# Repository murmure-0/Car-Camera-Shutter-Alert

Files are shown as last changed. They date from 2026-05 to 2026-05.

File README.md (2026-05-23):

# 🚗 Car Camera Shutter Alert

> 基于瑞芯微 RV1106 + STM32L4 的智能车载安全驾驶监控系统 — 集疲劳检测、手势识别、多传感器融合与 HUD 显示于一体


[]()
[]()
[]()

---

## 📖 项目简介

Car Camera Shutter Alert 是一套面向嵌入式车载场景的智能安全驾驶辅助系统，运行在瑞芯微 RV1106 嵌入式平台与 STM32L431 微控制器之上。系统通过摄像头实时采集驾驶员面部图像，利用 NPU 加速的深度学习模型进行人脸检测与关键点提取，计算 EAR（眼睛纵横比）、MAR（嘴巴纵横比）、PERCLOS 等疲劳指标，实现实时疲劳驾驶预警。同时集成百度手势识别 API，支持通过手势控制音乐播放，提升驾驶安全性与便利性。

### ✨ 核心特性

- **🧠 实时疲劳检测** — 基于 RetinaFace + PFLD 的多指标疲劳判定（EAR/MAR/PERCLOS/连续闭眼/连续张嘴）
- **🤚 手势识别控制** — 百度云端手势识别 API，支持握拳暂停、张手播放、食指上一首、数字二下一首
- **📹 视频录制** — 摄像头实时预览与录制状态管理
- **🗺️ GPS 定位** — GPS 模块 NMEA 解析 + 百度静态地图展示
- **🌡️ 环境监测** — 温湿度（AHT30）、加速度/陀螺仪（MPU6050）、电压/电流（INA226）、电池/霍尔传感器
- **🎵 音乐播放** — 本地音乐播放器，支持手势控制
- **📊 HUD 仪表盘** — 800×480 暗色主题 UI，人工地平仪、折线图、地图背景等 HUD 组件
- **🔌 双 MCU 串口通信** — STM32 与 RV1106 通过 UART JSON 协议实时交互传感器数据与控制指令
- **⚙️ 步进电机控制** — 支持摄像头遮挡盖板自动开合

---

## 🔧 硬件外观

<p align="center">
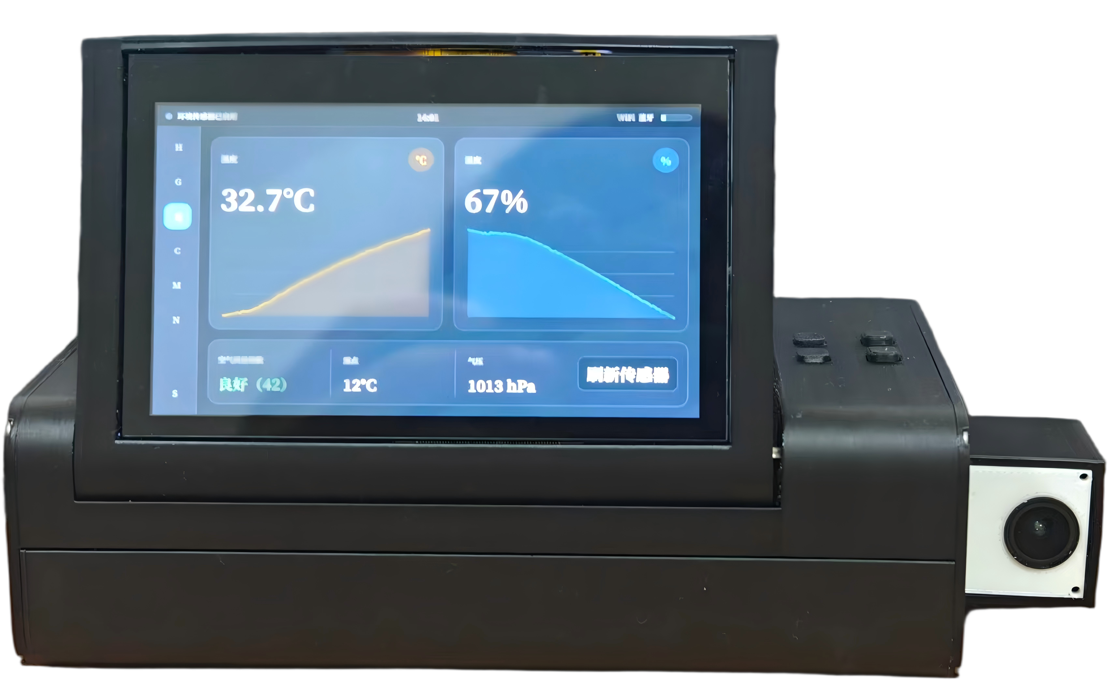
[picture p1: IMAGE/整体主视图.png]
Front View
  
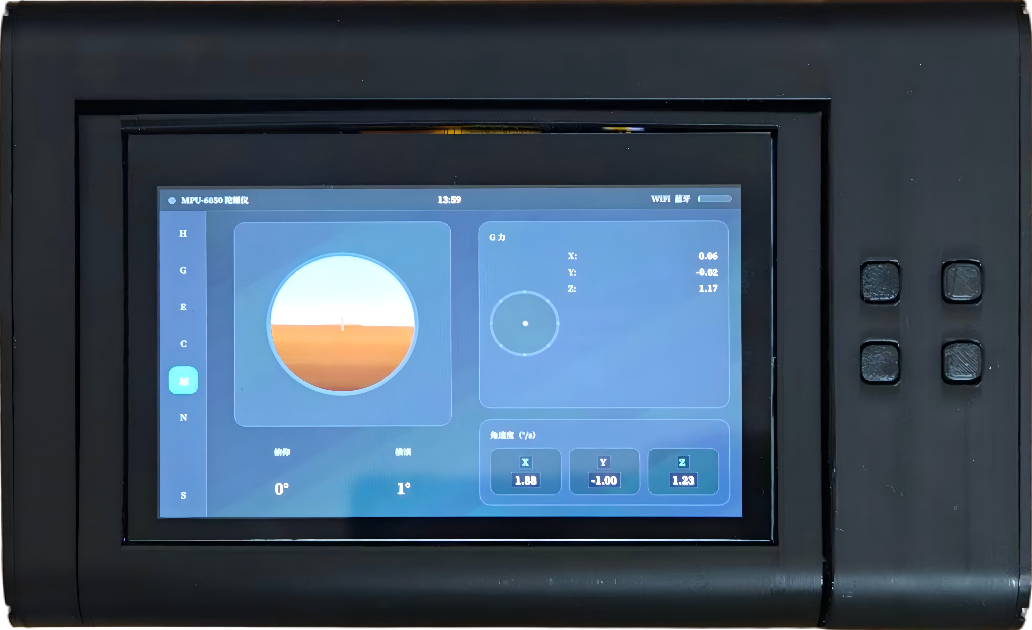
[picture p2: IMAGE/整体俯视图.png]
Top View
  
</p>

---

## 🏗️ 系统架构

```
┌─────────────────────────────────────────────────────────────────┐
│                    RV1106 主控板 (Linux)                         │
│  ┌──────────────────────────────────────────────────────────┐    │
│  │              Qt5 车机 UI (qt_car_ui)                      │   │
│  │  ┌──────┐ ┌──────┐ ┌──────┐ ┌──────┐ ┌──────┐ ┌──────┐   │    │
│  │  │仪表盘 │ │ GPS  │ │环境  │ │摄像头 │ │运动  │ │设置   │  │    │
│  │  └──────┘ └──────┘ └──────┘ └──┬───┘ └──────┘ └──────┘   │   │
│  └──────────────────────────────┼───────────────────────────┘   │
│                                 │                                │
│  ┌──────────────────────────────┼───────────────────────────┐   │
│  │        AI 推理引擎           │                           │   │
│  │  ┌─────────────┐  ┌─────────┴────────┐                  │   │
│  │  │ RetinaFace  │  │ PFLD 关键点检测  │                  │   │
│  │  │ 人脸检测    │  │ 106点关键点      │                  │   │
│  │  └──────┬──────┘  └────────┬─────────┘                  │   │
│  │         └────────┬─────────┘                             │   │
│  │                  ▼                                        │   │
│  │         ┌─────────────────┐                              │   │
│  │         │  疲劳指标计算    │                              │   │
│  │         │  EAR/MAR/PERCLOS│                              │   │
│  │         └─────────────────┘                              │   │
│  └──────────────────────────────────────────────────────────┘   │
│  ┌──────────────────────────────────────────────────────────┐   │
│  │  百度手势识别 API (BaiduGestureClient)                    │   │
│  └──────────────────────────────────────────────────────────┘   │
│                                                                 │
│  UART (ttyS0/ttyS1, 115200bps) ◄──── JSON 协议 ────►          │
└─────────────────────────────────────────────────────────────────┘
                              │
                              ▼
┌─────────────────────────────────────────────────────────────────┐
│                  STM32L431 传感器控制板 (FreeRTOS)               │
│  ┌────────┐ ┌────────┐ ┌────────┐ ┌────────┐ ┌────────┐         │
│  │MPU6050 │ │ AHT30  │ │ INA226 │ │  GPS   │ │步进电机│          │
│  │加速度  │ │温湿度  │ │电压电流│ │定位    │ │遮挡盖  │            │
│  └────────┘ └────────┘ └────────┘ └────────┘ └────────┘         │
│  ┌────────┐ ┌────────┐ ┌────────┐                               │
│  │ADC采集 │ │按键    │ │LED指示 │                                │
│  │电池/霍尔│ │开关机  │ │状态    │                                │
│  └────────┘ └────────┘ └────────┘                               │
└─────────────────────────────────────────────────────────────────┘
```

---

## 📁 项目结构

```
Car-Camera-Shutter-Alert/
├── qt_car_ui/                      # RV1106 端 Qt5 车机 UI 应用
│   ├── main.cpp                    # 应用入口
│   ├── mainwindow.h/cpp/ui         # 主窗口（页面路由、缩放适配、全局状态）
│   ├── baidu_gesture_client.h/cpp  # 百度手势识别 API 客户端
│   ├── camera/
│   │   ├── camera_service.h        # 摄像头硬件服务（MPI/ISP）
│   │   └── luckfox_mpi.cc          # Luckfox Pico MPI 封装
│   ├── pages/
│   │   ├── camerapage.h/cpp        # 摄像头页面（预览、疲劳检测、手势识别）
│   │   ├── dashboardpage.h/cpp     # 仪表盘页面（地图、音乐、系统监控）
│   │   ├── gpspage.h/cpp           # GPS 定位页面
│   │   ├── environmentpage.h/cpp   # 环境监测页面
│   │   ├── motionpage.h/cpp        # 运动姿态页面
│   │   ├── connectivitypage.h/cpp  # 网络连接页面
│   │   ├── settingspage.h/cpp      # 系统设置页面
│   │   ├── hudwidgets.h            # HUD 自定义控件（地平仪、折线图、预览等）
│   │   └── camerahud.h/cpp         # 摄像头 HUD 叠加层
│   ├── luckfox_pico_yolov5/
│   │   ├── include/
│   │   │   ├── yolov5.h            # YOLOv5 RKNN 模型上下文
│   │   │   ├── postprocess.h       # YOLOv5 后处理
│   │   │   ├── fatigue_runner.h    # 疲劳检测推理引擎
│   │   │   └── handyolo_runner.h   # 手部 YOLO 检测器
│   │   └── src/
│   │       ├── yolov5_runner.cpp
│   │       ├── fatigue_runner.cpp
│   │       └── handyolo_runner.cpp
│   ├── include/                    # 第三方库与平台头文件
│   │   ├── 3rdparty/               # RKNPU2、librga、DMA/DRM 分配器
│   │   ├── common/                 # ISP、sample_comm 公共代码
│   │   └── include/                # Rockchip MPI、RGA、RKAIQ 等平台头文件
│   ├── docs/
│   │   ├── camera_page_flow.md     # 摄像头页面运行流程分析
│   │   └── thread_resource_analysis.md  # 线程资源管理分析
│   └── qt_car_ui.pro               # Qt 项目文件
│
├── rv1106_sensor/                  # STM32L431 传感器控制板固件
│   ├── Core/
│   │   ├── Inc/                    # 头文件
│   │   │   ├── main.h
│   │   │   ├── bsp_power.h         # 电源管理
│   │   │   ├── mpu6050.h           # MPU6050 IMU 驱动
│   │   │   ├── aht30.h             # AHT30 温湿度驱动
│   │   │   ├── ina226.h            # INA226 功率监测驱动
│   │   │   ├── gps_module.h        # GPS 模块驱动
│   │   │   ├── stepper.h           # 步进电机驱动
│   │   │   ├── soft_i2c.h          # 软件 I2C 驱动
│   │   │   ├── key_handler.h       # 按键处理
│   │   │   ├── task_queue.h        # FreeRTOS 消息队列
│   │   │   ├── business_handler.h  # 业务逻辑处理
│   │   │   ├── protocol.h          # 串口通信协议
│   │   │   └── json_parser.h       # JSON 解析器
│   │   └── Src/                    # 源文件
│   ├── Drivers/                    # STM32 HAL/CMSIS 库
│   ├── MDK-ARM/                    # Keil MDK 工程文件
│   ├── README.md                   # STM32 子项目说明
│   └── PROTOCOL.md                 # STM32-RV1106 通信协议文档
│
├── 3d_model_assets/                # SolidWorks 3D 外壳模型
├── PCB/                            # PCB 工程文件
├── LICENSE                         # MIT 许可证
├── CONTRIBUTING.md                 # 贡献指南
└── README.md                       # 本文件
```

---

## 🚀 快速开始

### 前置条件

#### RV1106 端 (Qt5 UI)

- **硬件**: Luckfox Pico RV1106 开发板
- **交叉编译工具链**: arm-linux-gnueabihf-gcc
- **Qt5**: 交叉编译的 Qt5 for ARM (含 network、serialport 模块)
- **RKNN SDK**: rknpu2 运行时库 (armhf-uclibc)
- **Rockchip MPI**: librockit、librockchip_mpp、librga、librkaiq
- **OpenCV**: 交叉编译的 OpenCV for ARM
- **百度智能云 API Key**: 用于手势识别服务

#### STM32 端 (传感器固件)

- **硬件**: STM32L431RCT6 最小系统板
- **IDE**: Keil MDK-ARM v5
- **SDK**: STM32L4xx HAL Driver + CMSIS
- **RTOS**: FreeRTOS

### 编译与部署

#### 1. Qt5 车机 UI 编译

```bash
# 克隆仓库
git clone https://github.com/<your-username>/Car-Camera-Shutter-Alert.git
cd Car-Camera-Shutter-Alert/qt_car_ui

# 配置百度 API 凭证（环境变量方式）
export BAIDU_API_KEY="your_api_key"
export BAIDU_SECRET_KEY="your_secret_key"

# 如需使用自定义代理服务器（可选，默认直连百度云）
# export BAIDU_PROXY_BASE="http://your-proxy-server:8081"

# 使用交叉编译工具链构建
mkdir build && cd build
<qt-install-path>/bin/qmake ../qt_car_ui.pro -spec linux-arm-gnueabi-g++
make -j$(nproc)

# 部署到 RV1106 开发板
scp qt_car_ui root@<device-ip>:/opt/qt_car_ui/bin/
```

#### 2. STM32 固件编译

1. 使用 Keil MDK-ARM 打开 `rv1106_sensor/MDK-ARM/rv1106_sensor.uvprojx`
2. 选择目标芯片 STM32L431RCTx
3. 编译并下载到开发板

### 运行

在 RV1106 开发板上：

```bash
# 确保 RKNN 模型文件已部署到 ./model/ 目录
ls ./model/
# RetinaFace640.rknn  pfld_106.rknn

# 运行车机 UI
./qt_car_ui
```

---

## 🔧 功能详解

### 疲劳检测

系统采用多指标融合的疲劳判定策略：

| 指标 | 含义 | 阈值 | 判定条件 |
|---|---|---|---|
| **EAR** | 眼睛纵横比 | < 0.22 | 单眼闭合 |
| **MAR** | 嘴巴纵横比 | > 0.60 | 打哈欠 |
| **PERCLOS** | 滑动窗口闭眼占比 | > 0.50 | 持续疲劳（需≥100帧数据） |
| **连续闭眼帧** | 持续闭眼帧计数 | ≥ 15 帧 | 瞌睡 |
| **连续张嘴帧** | 持续张嘴帧计数 | ≥ 20 帧 | 打哈欠 |

任一指标触发即判定为疲劳状态，系统将：
- 在摄像头预览界面显示红色警告框和疲劳指标
- 通过串口发送疲劳状态到 STM32
- 在仪表盘页面触发疲劳警告音

### 手势识别

通过百度云端手势识别 API 实现，支持以下手势映射：

| 手势 | 动作 | 说明 |
|---|---|---|
| ✊ Fist (握拳) | ⏸ 暂停 | 暂停音乐播放 |
| 🖐 Five (张手) | ▶ 播放 | 恢复音乐播放 |
| ☝️ One (食指) | ⏮ 上一首 | 切换到上一首歌曲 |
| ✌️ Two (数字二) | ⏭ 下一首 | 切换到下一首歌曲 |

手势识别结果同时通过串口发送到 STM32，JSON 格式：
```json
{"type":"gesture","data":{"gesture":"Fist","action":"pause"}}
```

### 串口通信协议

STM32 与 RV1106 之间通过 UART (115200bps, 8N1) 进行 JSON 文本行通信：

- **STM32 → RV1106**: 周期性上报传感器数据（温度、湿度、加速度、陀螺仪、电压、电流、GPS、电池、霍尔、电机角度）
- **RV1106 → STM32**: 发送疲劳状态、网络状态、手势识别结果

详细协议规范见 [rv1106_sensor/PROTOCOL.md](rv1106_sensor/PROTOCOL.md)

---

## 🖼️ 界面展示

系统采用 800×480 暗色主题 UI，包含 7 个功能页面：

| 页面 | 导航键 | 功能 |
|---|---|---|
| 仪表盘 | H | 百度地图背景、音乐播放器、CPU/内存/温度监控 |
| GPS | G | GPS 坐标显示、卫星数量、百度静态地图 |
| 环境 | E | 温湿度、电池电压、功率监测 |
| 摄像头 | C | 实时预览、人脸检测框、疲劳指标叠加、手势识别 |
| 运动 | M | 人工地平仪、加速度/陀螺仪折线图、倾覆警告 |
| 网络 | N | 网络连接状态、IP 地址 |
| 设置 | S | 暗色/亮色主题切换、音量调节 |

---

## 🛠️ 技术栈

| 组件 | 技术 |
|---|---|
| 主控芯片 | 瑞芯微 RV1106 (ARM Cortex-A7 + NPU) |
| 传感器 MCU | STM32L431RCT6 (ARM Cortex-M4) |
| UI 框架 | Qt 5 (C++17) |
| AI 推理 | RKNPU2 (RKNN 零拷贝 API) |
| 人脸检测 | RetinaFace640 (RKNN 量化模型) |
| 关键点检测 | PFLD 106点 (RKNN 量化模型) |
| 手势识别 | 百度智能云手势识别 API |
| 地图服务 | 百度地图静态图 API |
| RTOS | FreeRTOS |
| 3D 建模 | SolidWorks |
| PCB 设计 | 立创 EDA |

---

## 📚 文档

- [摄像头页面运行流程分析](qt_car_ui/docs/camera_page_flow.md) — 详细的数据流、线程架构与生命周期
- [线程资源管理分析](qt_car_ui/docs/thread_resource_analysis.md) — 线程阻塞点排查与优化建议
- [STM32 模块说明](rv1106_sensor/项目模块说明.md) — 传感器驱动与 FreeRTOS 任务架构
- [通信协议文档](rv1106_sensor/PROTOCOL.md) — STM32-RV1106 JSON 串口协议
- [GPS 串口问题排查](rv1106_sensor/gps_uart_issue_record.md) — FreeRTOS 堆栈溢出排查案例

---

## 🤝 贡献指南

欢迎对本项目做出贡献！请阅读 [CONTRIBUTING.md](CONTRIBUTING.md) 了解详情。

### 快速贡献流程

1. Fork 本仓库
2. 创建功能分支 (`git checkout -b feature/amazing-feature`)
3. 提交更改 (`git commit -m 'Add some amazing feature'`)
4. 推送到分支 (`git push origin feature/amazing-feature`)
5. 创建 Pull Request

---

## 📄 许可证

本项目基于 [MIT License](LICENSE) 开源。

### 第三方库许可证

| 库 | 许可证 |
|----|---|
| Qt5 | LGPL v3 |
| RKNPU2 | Apache 2.0 |
| OpenCV | Apache 2.0 |
| STM32 HAL | BSD-3-Clause |
| FreeRTOS | MIT |

---

## 🙏 致谢

- [瑞芯微电子](https://www.rock-chips.com/) — RV1106 芯片与 RKNN SDK
- [百度智能云](https://cloud.baidu.com/) — 手势识别与地图 API
- [Luckfox Pico](https://www.luckfox.com/) — RV1106 开发板
- [STMicroelectronics](https://www.st.com/) — STM32 HAL 库
- [FreeRTOS](https://www.freertos.org/) — 实时操作系统

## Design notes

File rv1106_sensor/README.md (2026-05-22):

# STM32 Sensor Hub Project

This project implements drivers for various sensors and modules connected to an STM32 microcontroller (STM32L4 series).

## Hardware Configuration

### Pin Definitions

| Module | Pin Name | GPIO | Description |
| :--- | :--- | :--- | :--- |
| **Power Control** | BOOST_EN | PA1 | Total Sensor Power Enable (Active High) |
| | RV1106_POWER_EN | PC13 | RV1106 Core Board Power Enable (Active High) |
| **Hall Sensor** | IN_HALL_ADC1 | PC0 | Analog Input 1 |
| | IN_HALL_ADC2 | PC1 | Analog Input 2 |
| **Battery** | BAT_ADC_IN | PC2 | Battery Voltage Analog Input |
| | BAT_ADC_EN | PC3 | Battery Measure Enable (Active High) |
| **GPS** | GPS_TX | PA2 | UART TX |
| | GPS_RX | PA3 | UART RX |
| | GPS_WAKE | PA6 | Wakeup / Power Control |
| **Host Comms** | STM32_TX | PC4 | UART to RV1106 |
| | STM32_RX | PC5 | UART from RV1106 |
| **MPU6050** | SDA | PB10 | I2C Data (Software) |
| | SCL | PB11 | I2C Clock (Software) |
| **AHT30** | SDA | PA15 | I2C Data (Software) |
| | SCL | PC10 | I2C Clock (Software) |
| **INA226** | SCL | PC11 | I2C Clock (Software) |
| | SDA | PC12 | I2C Data (Software) |
| **Stepper** | STEP_D0 | PD2 | Coil Driver 0 |
| | STEP_D1 | PB3 | Coil Driver 1 |
| | STEP_D2 | PB4 | Coil Driver 2 |
| | STEP_D3 | PB5 | Coil Driver 3 |

## Software Modules

### 1. Power Control (`bsp_power.h`)
Manages power rails for sensors and external modules.
- `BSP_Power_SetSensorPower(1)`: Enables `BOOST_EN` (Sensors).
- `BSP_Power_SetRV1106Power(1)`: Enables `RV1106_POWER_EN` (RV1106 Board).

### 2. Software I2C Driver (`soft_i2c.h`)
A generic bit-banging I2C driver supporting multiple instances.
- **Initialization**: `SoftI2C_Init(&handle)`
- **Usage**: Populate `SoftI2C_Handle_t` with SCL/SDA ports and pins.

### 3. MPU6050 IMU (`mpu6050.h`)
Driver for MPU6050 Accelerometer and Gyroscope.
- **Features**: Reads 6-axis data and temperature.
- **Interface**: Software I2C.

### 4. AHT30 Temperature & Humidity (`aht30.h`)
Driver for AHT30 sensor.
- **Features**: Reads relative humidity and temperature.
- **Interface**: Software I2C.

### 5. INA226 Power Monitor (`ina226.h`)
Driver for INA226 Voltage and Current sensor.
- **Features**: Reads Bus Voltage, Shunt Voltage, Current, and Power.
- **Interface**: Software I2C.
- **Note**: Calibration must be set via `INA226_SetCalibration` for correct Current/Power readings.

### 6. GPS Module (`gps_module.h`)
Driver for GPS module control and NMEA parsing.
- **Protocol**: NMEA 0183 (GNGGA sentence supported).
- **Features**: Wakeup control, Coordinate parsing.
- **Power**: Controlled via `BSP_Power_SetSensorPower`.

### 7. Stepper Motor (`stepper.h`)
Simple driver for 4-phase stepper motor.
- **Features**: Step generation with delay control.

### 8. BSP ADC (`bsp_adc.h`)
Helper functions for analog readings.
- **Features**: 
  - `BSP_GetBatteryVoltage()`: Handles Enable pin automatically.
  - `BSP_GetHallSensorX()`: Reads Hall sensor analog values.

## Usage Example

```c
#include "bsp_power.h"
#include "mpu6050.h"

SoftI2C_Handle_t hi2c_mpu = {GPIOB, GPIO_PIN_11, GPIOB, GPIO_PIN_10}; // SCL, SDA

void main() {
    HAL_Init();
    SystemClock_Config();
    MX_GPIO_Init();
    
    // 1. Turn on Sensor Power
    BSP_Power_Init();
    BSP_Power_SetSensorPower(1);
    HAL_Delay(100); // Wait for power stable
    
    // 2. Init MPU6050
    SoftI2C_Init(&hi2c_mpu);
    if (MPU6050_Init(&hi2c_mpu) == 0) {
        // Init Success
    }
    
    // 3. Turn on RV1106
    BSP_Power_SetRV1106Power(1);
    
    while(1) {
        // ...
    }
}
```

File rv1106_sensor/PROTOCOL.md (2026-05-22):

# STM32 - RV1106 通信协议文档

本文档描述了 STM32 传感器控制板与 RV1106 主控板之间的通信协议。

## 1. 物理层
*   **接口**: UART (TTL电平)
*   **波特率**: 115200 (默认) / 9600
*   **数据位**: 8
*   **停止位**: 1
*   **校验位**: 无
*   **流控**: 无

## 2. 协议格式
通信采用 **JSON 文本行** 格式。每条消息占一行，以换行符 `\n` (0x0A) 结尾。

### 2.1 STM32 -> RV1106 (传感器数据上报)
STM32 周期性（例如 2Hz）发送包含所有传感器状态的 JSON 对象。

**示例数据包:**
```json
{
  "temp": 25.50,
  "humi": 60.20,
  "mpu": {
    "ax": 0.02,
    "ay": 0.05,
    "az": 1.01,
    "gx": 0.01,
    "gy": -0.02,
    "gz": 0.00,
    "t": 26.5,
    "ang": {
      "roll": 1.50,
      "pitch": -0.80,
      "yaw": 12.30
    }
  },
  "pwr": {
    "v": 5.05,
    "vs": 2.50,
    "i": 0.1500,
    "p": 0.7575
  },
  "adc": {
    "bat": 4.15,
    "h1": 2048,
    "h2": 2050
  },
  "gps": {
    "lat": 0.000000,
    "lon": 0.000000,
    "sat": 0
  },
  "motor": {
    "ang": 15.50
  }
}
```

**字段说明:**

| 根键 | 子键 | 类型 | 单位 | 说明 |
| :--- | :--- | :--- | :--- | :--- |
| `temp` | - | float | °C | AHT30 环境温度 |
| `humi` | - | float | %RH | AHT30 环境湿度 |
| `mpu` | `ax`, `ay`, `az` | float | g | 三轴加速度 |
| `mpu` | `gx`, `gy`, `gz` | float | deg/s | 三轴角速度 |
| `mpu` | `t` | float | °C | MPU6050 芯片温度 |
| `mpu` | `ang.roll` | float | deg | 横滚角 |
| `mpu` | `ang.pitch` | float | deg | 俯仰角 |
| `mpu` | `ang.yaw` | float | deg | 偏航角 |
| `pwr` | `v` | float | V | 总线电压 (INA226) |
| `pwr` | `vs` | float | mV | 分流电阻电压 (INA226) |
| `pwr` | `i` | float | A | 电流 (INA226) |
| `pwr` | `p` | float | W | 功率 (INA226) |
| `adc` | `bat` | float | V | 电池电压 |
| `adc` | `h1` | int | - | 霍尔传感器1原始ADC值 (0-4095) |
| `adc` | `h2` | int | - | 霍尔传感器2原始ADC值 (0-4095) |
| `gps` | `lat` | float | deg | 纬度 |
| `gps` | `lon` | float | deg | 经度 |
| `gps` | `sat` | int | - | 卫星数量 |
| `motor` | `ang` | float | deg | 步进电机当前角度 (累积值) |

### 2.2 RV1106 -> STM32 (控制指令 - 预留)
目前协议主要为单向上传。如果需要控制（例如控制电机），建议采用以下 JSON 格式：

**电机控制示例:**
```json
{"cmd":"motor_move", "steps": 100, "speed": 2}
```

**复位指令:**
```json
{"cmd":"system_reset"}
```

## 3. 注意事项
1.  **浮点精度**: JSON 中的浮点数保留 2-6 位小数，具体取决于字段重要性。
2.  **解析**: 接收端应使用标准 JSON 解析器（如 Python `json` 库或 C++ `cJSON`）。
3.  **角度**: `motor.ang` 是基于步数的累积计算值。系统上电时默认为 0 度。如果电机丢步，该值可能会有偏差。

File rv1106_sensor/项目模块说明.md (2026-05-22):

# STM32 传感器系统模块说明

## 项目概述

本项目是一个基于 STM32 的多传感器数据采集与控制系统，集成了 MPU6050、AHT30、INA226、GPS 等传感器，支持步进电机控制、按键交互和 RV1106 电源管理。

---

## 模块架构

```
┌─────────────────────────────────────────────────────────────┐
│                      业务处理模块                              │
│                  (business_handler.c)                        │
│  ┌──────────────┐  ┌──────────────┐  ┌──────────────┐      │
│  │  按键处理    │  │  传感器处理  │  │  GPS处理    │      │
│  └──────────────┘  └──────────────┘  └──────────────┘      │
└─────────────────────────────────────────────────────────────┘
                         ▲
                         │ 消息队列
                         │
┌─────────────────────────────────────────────────────────────┐
│                      消息队列模块                             │
│                    (task_queue.c)                            │
│  ┌──────────────────────────────────────────────────────┐   │
│  │  FreeRTOS 消息队列 (16个消息深度)                     │   │
│  │  消息类型：按键、传感器、GPS                          │   │
│  └──────────────────────────────────────────────────────┘   │
└─────────────────────────────────────────────────────────────┘
                         ▲
                         │ 发送消息
                         │
┌─────────────────────────────────────────────────────────────┐
│                      按键处理模块                             │
│                    (key_handler.c)                           │
│  ┌──────────────┐  ┌──────────────┐  ┌──────────────┐      │
│  │  PA0按键     │  │  PC1_KEY1    │  │  PC1_KEY2    │      │
│  │  (开关机)    │  │  (短按/长按) │  │  (短按/长按) │      │
│  └──────────────┘  └──────────────┘  └──────────────┘      │
│  ┌──────────────┐                                            │
│  │  PC1_KEY3    │                                            │
│  │  (短按/长按) │                                            │
│  └──────────────┘                                            │
└─────────────────────────────────────────────────────────────┘
                         ▲
                         │
┌─────────────────────────────────────────────────────────────┐
│                      传感器采集模块                           │
│                  (defaultTask)                               │
│  ┌──────────────┐  ┌──────────────┐  ┌──────────────┐      │
│  │  MPU6050     │  │  AHT30       │  │  INA226      │      │
│  │  (加速度/陀螺)│  │  (温湿度)    │  │  (电压/电流) │      │
│  └──────────────┘  └──────────────┘  └──────────────┘      │
│  ┌──────────────┐  ┌──────────────┐                         │
│  │  ADC         │  │  步进电机    │                         │
│  │  (电池/霍尔)  │  │  (角度反馈)  │                         │
│  └──────────────┘  └──────────────┘                         │
└─────────────────────────────────────────────────────────────┘
```

---

## 文件功能说明

### 1. 主程序文件

#### `main.c`
**功能**：系统初始化和主循环

**主要职责**：
- MCU 复位和时钟配置
- GPIO、ADC、UART 初始化
- 传感器上电和初始化
- FreeRTOS 初始化
- 启动调度器

**关键函数**：
- `main()` - 系统入口点
- `SystemClock_Config()` - 系统时钟配置
- `MX_FREERTOS_Init()` - FreeRTOS 初始化

**初始化流程**：
1. 电源初始化（传感器电源、RV1106电源）
2. I2C 总线初始化（MPU6050、AHT30、INA226）
3. 传感器初始化（MPU6050、AHT30、INA226）
4. 步进电机初始化
5. GPS 模块初始化
6. FreeRTOS 任务创建

---

### 2. 任务队列模块

#### `task_queue.h`
**功能**：消息队列头文件，定义消息类型和接口

**主要定义**：
- `TaskMsgType_t` - 消息类型枚举
  - `TASK_MSG_KEY_PRESS` - 按键消息
  - `TASK_MSG_SENSOR_UPDATE` - 传感器更新
  - `TASK_MSG_GPS_UPDATE` - GPS 更新
  
- `KeyMsg_t` - 按键消息结构
  - `key_id` - 按键ID (0=PA0, 1-3=PC1按键)
  - `press_type` - 按键类型 (0=短按, 1=长按)
  
- `SensorMsg_t` - 传感器消息结构
- `GPSMsg_t` - GPS 消息结构
- `TaskMsg_t` - 通用消息结构（使用 union）

**导出函数**：
- `TaskQueue_Init()` - 初始化消息队列
- `TaskQueue_SendKeyMsg()` - 发送按键消息
- `TaskQueue_SendSensorMsg()` - 发送传感器消息
- `TaskQueue_SendGPSMsg()` - 发送GPS消息
- `TaskQueue_ReceiveMsg()` - 接收消息

#### `task_queue.c`
**功能**：消息队列实现

**主要实现**：
- 创建 FreeRTOS 消息队列（16个消息深度）
- 实现消息发送和接收函数
- 消息数据打包和解包

**队列配置**：
- 队列长度：16
- 消息大小：`sizeof(TaskMsg_t)`

---

### 3. 按键处理模块

#### `key_handler.h`
**功能**：按键处理头文件

**主要定义**：
- `KEY_ID_PA0` - PA0独立按键
- `KEY_ID_PC1_KEY1` - PC1 ADC按键1
- `KEY_ID_PC1_KEY2` - PC1 ADC按键2
- `KEY_ID_PC1_KEY3` - PC1 ADC按键3
- `KEY_PRESS_SHORT` - 短按
- `KEY_PRESS_LONG` - 长按

**导出函数**：
- `KeyHandler_Init()` - 按键初始化
- `KeyHandler_ScanTask()` - 按键扫描任务
- `KeyHandler_GetKeyState()` - 获取按键状态

#### `key_handler.c`
**功能**：按键检测和消息发送

**主要职责**：
- 轮询扫描所有按键状态
- 检测按键按下和松开事件
- 检测长按（持续2秒以上）
- 通过消息队列发送按键事件

**按键检测逻辑**：
1. **PC1 ADC按键**：
   - 读取 ADC 值判断按键类型
   - 记录按下时间
   - 2秒内松开 → 短按
   - 持续2秒 → 长按

2. **PA0独立按键**：
   - 读取 GPIO 状态
   - 同样的长按检测逻辑

**时间配置**：
- 扫描周期：100ms
- 长按阈值：2000ms (2秒)

---

### 4. 业务处理模块

#### `business_handler.h`
**功能**：业务处理头文件

**导出函数**：
- `BusinessHandler_Init()` - 业务处理初始化
- `BusinessHandler_Task()` - 业务处理任务
- `BusinessHandler_ProcessKeyEvent()` - 处理按键事件
- `BusinessHandler_ProcessSensorUpdate()` - 处理传感器更新
- `BusinessHandler_ProcessGPSUpdate()` - 处理GPS更新

#### `business_handler.c`
**功能**：业务逻辑处理

**主要职责**：
- 接收消息队列中的消息
- 根据消息类型分发到对应的处理函数
- 实现具体的业务逻辑

**按键处理逻辑**：

1. **PA0 长按** - 开关机控制
   ```c
   if (rv1106_power_on == 0) {
       // 开机流程
       Stepper_SetAngle(60.0f);     // 电机转到60度
       BSP_Power_SetRV1106Power(1); // 打开RV1106电源
       rv1106_power_on = 1;
   } else {
       // 关机流程
       Stepper_SetAngle(0.0f);      // 电机转到0度
       BSP_Power_SetRV1106Power(0); // 关闭RV1106电源
       rv1106_power_on = 0;
   }
   ```

2. **PC1 按键** - 状态输出
   - 短按：输出按键名称
   - 长按：输出按键名称 + "_LONG"

**扩展点**：
- 所有处理函数都预留了 TODO 注释
- 可以轻松添加新的业务逻辑

---

### 5. 传感器采集模块

#### `freertos.c` - `StartDefaultTask`
**功能**：传感器数据采集任务

**主要职责**：
- 定期采集所有传感器数据
- 计算姿态角（俯仰、横滚、航向）
- 发送传感器数据

**采集数据**：
1. **MPU6050**：
   - 加速度（X/Y/Z）
   - 陀螺仪（X/Y/Z）
   - 温度
   - 计算：俯仰角、横滚角、航向角

2. **AHT30**：
   - 温度
   - 湿度

3. **INA226**：
   - 总线电压
   - 分流电压
   - 电流
   - 功率

4. **ADC**：
   - 电池电压
   - 霍尔传感器1
   - 霍尔传感器2

5. **步进电机**：
   - 当前角度

**发送频率**：每 200ms 发送一次（两次间隔100ms）

---

#### `freertos.c` - `StartGpsBridgeTask`
**功能**：GPS 数据桥接任务

**主要职责**：
- 从 UART2 接收 GPS NMEA 数据
- 解析 GNGGA 帧
- 提取经纬度和卫星数量
- 更新全局变量

**数据流**：
```
GPS模块 → UART2 → NMEA解析 → g_gps_lat/g_gps_lon/g_gps_sat
```

---

#### `freertos.c` - `StartLedBlinkTask`
**功能**：LED 状态指示任务

**主要职责**：
- 每 500ms 翻转 LED 状态
- 提供系统运行指示

**LED 控制**：
- 翻转 PB 口的 LED_OUT1-4

---

### 6. 硬件驱动模块

#### `stepper.h/c`
**功能**：步进电机控制

**主要函数**：
- `Stepper_Init()` - 初始化电机
- `Stepper_Step(steps, delay)` - 步进运动
- `Stepper_SingleStep(direction)` - 单步运动
- `Stepper_ResetPosition()` - 重置位置
- `Stepper_GetAngle()` - 获取当前角度
- `Stepper_SetAngle(angle)` - 设置目标角度

**电机参数**：
- 步进电机型号：28BYJ-48
- 每转步数：2048
- 减速比：1:64

#### `bsp_power.h/c`
**功能**：电源管理

**主要函数**：
- `BSP_Power_Init()` - 电源初始化
- `BSP_Power_SetSensorPower(enable)` - 传感器电源控制
- `BSP_Power_SetRV1106Power(enable)` - RV1106电源控制

#### `bsp_adc.h/c`
**功能**：ADC 采集

**主要函数**：
- `BSP_ADC_ReadChannel(channel)` - 读取指定通道ADC值
- `BSP_GetBatteryVoltage()` - 获取电池电压
- `BSP_GetHallSensor1()` - 获取霍尔传感器1值

#### `mpu6050.h/c`
**功能**：MPU6050 传感器驱动

**主要函数**：
- `MPU6050_Init()` - 初始化传感器
- `MPU6050_Read_All()` - 读取所有数据

#### `aht30.h/c`
**功能**：AHT30 温湿度传感器驱动

**主要函数**：
- `AHT30_Init()` - 初始化传感器
- `AHT30_Read_Data()` - 读取温湿度数据

#### `ina226.h/c`
**功能**：INA226 电流电压传感器驱动

**主要函数**：
- `INA226_Init()` - 初始化传感器
- `INA226_Read_Data()` - 读取电流电压数据

#### `gps_module.h/c`
**功能**：GPS 模块驱动

**主要函数**：
- `GPS_Init()` - 初始化GPS
- `GPS_ParseGNGGA()` - 解析GNGGA帧

---

## 任务优先级

| 任务名称 | 优先级 | 说明 |
|---|---|---|
| gpsBridgeTask | AboveNormal | GPS数据接收需要及时处理 |
| defaultTask | Normal | 传感器数据采集 |
| keyScanTask | Normal | 按键扫描 |
| businessTask | Normal | 业务处理 |
| ledBlinkTask | Low | LED指示 |

---

## 消息类型说明

### 按键消息
```c
{
    type: TASK_MSG_KEY_PRESS,
    key_id: 0-3,           // 0=PA0, 1-3=PC1按键
    press_type: 0-1        // 0=短按, 1=长按
}
```

### 传感器消息
```c
{
    type: TASK_MSG_SENSOR_UPDATE,
    temperature: float,     // 温度
    humidity: float,        // 湿度
    battery_voltage: float, // 电池电压
    motor_angle: float      // 电机角度
}
```

### GPS消息
```c
{
    type: TASK_MSG_GPS_UPDATE,
    latitude: float,        // 纬度
    longitude: float,       // 经度
    satellites: uint8_t     // 卫星数量
}
```

---

## 扩展开发指南

### 添加新按键功能
1. 在 `key_handler.h` 中定义按键ID
2. 在 `business_handler.c` 的 `BusinessHandler_ProcessKeyEvent()` 中添加处理逻辑

### 添加新传感器
1. 创建传感器驱动模块（参考 mpu6050.c）
2. 在 `defaultTask` 中添加数据采集
3. 如需消息通知，在 `task_queue.h` 中添加消息类型

### 添加新业务逻辑
1. 在 `business_handler.h` 中声明处理函数
2. 在 `business_handler.c` 中实现处理逻辑
3. 在 `BusinessHandler_Task()` 的 switch 中添加分支

---

## 系统启动流程

```
1. HAL_Init()                    // 复位外设
2. SystemClock_Config()          // 配置系统时钟
3. MX_GPIO_Init()                // 初始化GPIO
4. MX_ADC1_Init()                // 初始化ADC
5. MX_USARTx_UART_Init()         // 初始化串口
6. BSP_Power_Init()              // 电源初始化
7. BSP_Power_SetSensorPower(1)   // 打开传感器电源
8. BSP_Power_SetRV1106Power(1)   // 打开RV1106电源
9. SoftI2C_Init()                // 初始化I2C
10. MPU6050_Init()               // 初始化MPU6050
11. AHT30_Init()                 // 初始化AHT30
12. INA226_Init()                // 初始化INA226
13. Stepper_Init()               // 初始化步进电机
14. GPS_Init()                   // 初始化GPS
15. TaskQueue_Init()             // 初始化消息队列
16. MX_FREERTOS_Init()           // 创建FreeRTOS任务
17. osKernelStart()              // 启动调度器
```

---

## 注意事项

1. **消息队列大小**：16个消息，如果消息产生速度过快可能丢失
2. **长按时间**：2秒，可在 `key_handler.c` 中修改
3. **传感器采集频率**：每 200ms 采集一次
4. **栈大小**：根据实际使用情况调整
5. **电源管理**：RV1106电源由 PA0 长按控制

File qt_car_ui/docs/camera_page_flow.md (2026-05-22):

# 摄像头页面运行流程分析

## 1. 系统启动与初始化

### 1.1 启动入口

`MainWindow` 构造函数中创建 `CameraPage`：

```
MainWindow::MainWindow()
  └─ m_cameraPage = new CameraPage(m_stack)    // mainwindow.cpp:L221
```

### 1.2 CameraPage 构造函数初始化流程

`CameraPage::CameraPage()` (camerapage.cpp:L145) 按以下顺序初始化：

```
CameraPage::CameraPage()
  ├─ 1. qRegisterMetaType<QVector<CameraDetectionOverlay>>()   // 注册跨线程信号类型
  ├─ 2. qRegisterMetaType<QStringList>()
  ├─ 3. 创建 CameraPreviewWidget（预览画面 + 检测框绘制）
  ├─ 4. 创建右侧信息面板（疲劳状态/EAR/MAR/PERCLOS/手势标签）
  ├─ 5. 创建 CameraCaptureWorker + QThread（采集线程）
  ├─ 6. 连接信号槽（帧数据 → UI更新）
  ├─ 7. 启动采集线程 thread->start()
  ├─ 8. 创建 BaiduGestureClient（手势识别客户端）
  ├─ 9. 创建 QTimer（1秒间隔，触发手势识别）
  └─ 10. 启动手势识别定时器 m_cloudTimer->start()
```

### 1.3 采集线程初始化

线程启动后，`CameraCaptureWorker::start()` 执行：

```
CameraCaptureWorker::start()                    // camerapage.cpp:L46
  ├─ m_service.init(640, 480)                   // 初始化摄像头硬件
  │   ├─ SAMPLE_COMM_ISP_Init(0, ...)           // ISP 初始化
  │   ├─ SAMPLE_COMM_ISP_Run(0)                 // ISP 运行
  │   ├─ RK_MPI_SYS_Init()                      // MPI 系统初始化
  │   ├─ vi_dev_init()                          // VI 设备初始化
  │   └─ vi_chn_init(0, 640, 480)              // VI 通道初始化
  │
  ├─ m_runner.init("./model/RetinaFace640.rknn", // 初始化人脸检测模型
  │                 "./model/pfld_106.rknn",      // 初始化关键点检测模型
  │                 112)                          // 关键点模型输入尺寸
  │   ├─ init_retinaface_model()                 // 加载 RetinaFace RKNN 模型
  │   │   ├─ rknn_init()                         // 创建 RKNN 上下文
  │   │   ├─ rknn_query(IN_OUT_NUM)              // 查询输入输出数量
  │   │   ├─ rknn_query(NATIVE_INPUT_ATTR)       // 查询输入属性
  │   │   └─ rknn_query(NATIVE_NHWC_OUTPUT_ATTR) // 查询输出属性
  │   │
  │   └─ m_pfldModel->init(pfld_rknn_path)       // 加载 PFLD 关键点模型
  │       ├─ rknn_init()
  │       ├─ rknn_query(...)
  │       └─ rknn_create_mem()                    // 分配零拷贝内存
  │
  └─ 进入采集循环 while(m_running)
```

---

## 2. 线程架构

### 2.1 线程总览

| 线程 | 类型 | 创建时机 | 主要职责 | 生命周期 |
|---|---|---|---|---|
| **UI 主线程** | Qt GUI 线程 | 程序启动 | 界面渲染、事件处理、手势API调用 | 程序全程 |
| **采集线程** | QThread | CameraPage构造时 | 摄像头抓帧 + 人脸检测 + 疲劳推理 | CameraPage存在期间 |
| **百度API网络线程** | Qt网络内部线程 | 首次HTTP请求时 | 发送图像到百度服务器，接收手势结果 | 异步，请求完成即结束 |

### 2.2 线程关系图

```
┌─────────────────────────────────────────────────────────────┐
│                     UI 主线程 (Main Thread)                   │
│                                                               │
│  ┌──────────────┐  ┌──────────────────┐  ┌───────────────┐  │
│  │CameraPreview │  │BaiduGestureClient│  │  QLabel(s)    │  │
│  │   Widget     │  │  (网络请求)       │  │ 疲劳/手势显示  │  │
│  └──────┬───────┘  └────────┬─────────┘  └───────┬───────┘  │
│         │                   │                     │           │
│         │  frameReady信号   │  inferenceFinished  │  更新文本  │
│         │  (跨线程)         │  信号               │           │
└─────────┼───────────────────┼─────────────────────┼───────────┘
          │                   │                     │
          ▲                   ▲                     ▲
          │                   │                     │
┌─────────┼───────────────────┼─────────────────────┼───────────┐
│         │    采集线程 (Capture QThread)             │           │
│         │                                               │       │
│  ┌──────┴───────┐                                       │       │
│  │CameraCapture │                                       │       │
│  │   Worker     │─── frameReady(img, detections, ──────┘       │
│  │              │               fatigueInfo)                    │
│  │  ┌─────────┐│                                              │
│  │  │Camera   ││  YUV→RGB 抓帧                                │
│  │  │Service  ││                                              │
│  │  └─────────┘│                                              │
│  │  ┌─────────┐│                                              │
│  │  │Fatigue  ││  人脸检测 + 关键点 + 疲劳判定                  │
│  │  │Detector ││                                              │
│  │  │Runner   ││                                              │
│  │  └─────────┘│                                              │
│  └──────────────┘                                              │
└─────────────────────────────────────────────────────────────────┘
```

---

## 3. 主循环数据流

### 3.1 采集线程主循环

```
while (m_running) {                                    // camerapage.cpp:L68
    │
    ├─ 1. 抓取原始帧
    │   m_service.grabFrameRGB(img, 1000)              // camera_service.h:L49
    │   输入: 无
    │   输出: QImage(640x480, RGB888)
    │   数据流: VI通道 → YUV420SP → 软件转RGB888 → QImage
    │
    ├─ 2. 图像预处理
    │   ├─ convertToFormat(Format_RGB888)              // 确保格式一致
    │   ├─ copy(x, y, 480, 480)                       // 中心裁剪 640x480→480x480
    │   └─ transformed(rotate(-90))                   // 逆时针旋转90°
    │   输出: QImage(480x480, RGB888) → cv::Mat(BGR)
    │
    ├─ 3. RetinaFace 人脸检测
    │   inference_retinaface_model(&m_retinafaceCtx,   // retinaface.cc
    │       frame.cols, frame.rows,
    │       rgb_data, step, &retina_result)
    │   输入: cv::Mat(BGR, 480x480)
    │   输出: retinaface_result { count, object[128] }
    │       每个 object: { cls, box{left,top,right,bottom}, score, ponit[5] }
    │
    ├─ 4. PFLD 关键点检测（对每张人脸）
    │   m_pfldModel->run(face_roi)                     // fatigue_runner.cpp
    │   输入: 人脸ROI区域 (cv::Mat)
    │   输出: 106个关键点坐标 (cv::Point2f)
    │
    ├─ 5. 疲劳指标计算
    │   ├─ EAR (Eye Aspect Ratio) 计算                 // 双眼纵横比
    │   ├─ MAR (Mouth Aspect Ratio) 计算               // 嘴巴纵横比
    │   ├─ PERCLOS 计算                                // 滑动窗口闭眼占比
    │   ├─ 连续闭眼帧计数
    │   └─ 连续张嘴帧计数
    │
    ├─ 6. 疲劳判定
    │   eye_fatigue = consecutiveEyeClosed >= 15
    │   mouth_fatigue = consecutiveMouthOpen >= 20
    │   perclos_fatigue = perclos > 0.5 (需≥100帧数据)
    │   is_tired = eye_fatigue || mouth_fatigue || perclos_fatigue
    │
    ├─ 7. 绘制标注图
    │   ├─ 人脸检测框（绿色正常/红色疲劳）
    │   ├─ 关键点连线
    │   └─ 疲劳指标文字
    │
    └─ 8. 发射信号
        emit frameReady(img, detections, fatigueInfo)  // 跨线程到UI
}
```

### 3.2 帧数据传输详情

| 阶段 | 数据类型 | 格式/尺寸 | 传输方向 |
|---|---|---|---|
| 摄像头输出 | YUV420SP | 640x480, stride对齐 | 硬件→CameraService |
| grabFrameRGB | QImage | 640x480, RGB888 | CameraService→Worker |
| 裁剪旋转后 | QImage | 480x480, RGB888 | Worker内部 |
| OpenCV转换 | cv::Mat | 480x480, CV_8UC3(BGR) | Worker→FatigueRunner |
| RetinaFace输出 | retinaface_result | 最多128个检测框 | FatigueRunner内部 |
| PFLD输出 | vector<Point2f> | 106个关键点 | FatigueRunner内部 |
| 标注图 | QImage | 480x480, RGB888 | FatigueRunner→Worker |
| frameReady信号 | QImage + QVector + QStringList | 跨线程 | Worker→UI主线程 |

---

## 4. 线程间通信机制

### 4.1 采集线程 → UI主线程

**信号**: `CameraCaptureWorker::frameReady`

```
信号定义 (camerapage.cpp:L36):
    void frameReady(const QImage &img,
                    const QVector<CameraDetectionOverlay> &detections,
                    const QStringList &fatigueInfo);

连接方式 (camerapage.cpp:L219):
    connect(worker, &CameraCaptureWorker::frameReady, m_preview, [...]);

数据传输:
    QImage img          → 预览画面（含标注）
    QVector<CameraDetectionOverlay> detections → 检测框信息
    QStringList fatigueInfo → 疲劳指标文本列表
```

由于信号从子线程发射到主线程，Qt 使用**队列连接（QueuedConnection）** 自动处理线程安全。这就是为什么需要在构造函数中 `qRegisterMetaType` 注册自定义类型。

### 4.2 UI主线程 → 百度API → UI主线程

**信号**: `BaiduGestureClient::inferenceFinished`

```
触发流程:
    m_cloudTimer (1秒间隔)
      → m_cloudClient->infer(m_lastFrame)     // 发送当前帧
        → requestToken()                       // 获取/刷新 access_token
          → HTTP POST → 百度OAuth2服务
          ← JSON {access_token, expires_in}
        → requestGesture(jpegBytes)            // 发送图像识别请求
          → HTTP POST → 百度手势识别API
          ← JSON {result: [{classname, probability}]}
      ← emit inferenceFinished(ok, lines)      // 返回识别结果

连接方式 (camerapage.cpp:L272):
    connect(m_cloudClient, &BaiduGestureClient::inferenceFinished, this, [...]);
```

### 4.3 CameraPage → MainWindow 信号

| 信号 | 触发条件 | 数据 | 接收处理 |
|---|---|---|---|
| `gestureDetected(QString)` | 百度API返回有效手势 | 手势名称如"Fist" | 音乐控制 + 串口发送JSON |
| `fatigueDetected(bool)` | 每帧疲劳判定结果 | true/false | 警告音控制 + 串口发送JSON |
| `toggleRecordingRequested()` | 录制按钮点击 | 无 | 切换录制状态 |

---

## 5. 关键数据结构

### 5.1 CameraDetectionOverlay

```cpp
// hudwidgets.h:L156
struct CameraDetectionOverlay {
    QRectF rect;      // 检测框在图像中的归一化坐标
    QString label;    // "FACE" 或 "TIRED"
    float score;      // 置信度
};
```

### 5.2 FatigueResult

```cpp
// fatigue_runner.h:L29
struct FatigueResult {
    std::vector<FatigueFaceResult> faces;
};

struct FatigueFaceResult {
    cv::Rect face_rect;                    // 人脸矩形
    bool is_tired;                         // 疲劳判定
    FatigueMetrics metrics;                // 疲劳指标
    std::vector<cv::Point2f> landmarks;    // 106个关键点
};

struct FatigueMetrics {
    float ear;                     // 眼睛纵横比
    float mar;                     // 嘴巴纵横比
    float perclos;                 // 闭眼时间占比
    int consecutive_eye_closed;    // 连续闭眼帧数
    int consecutive_mouth_open;    // 连续张嘴帧数
};
```

### 5.3 retinaface_result

```cpp
// retinaface_facenet.h:L37
typedef struct {
    int count;                              // 检测到的人脸数量
    retinaface_object_t object[128];        // 最多128个检测结果
} retinaface_result;

typedef struct retinaface_object_t {
    int cls;                    // 类别
    box_rect_t box;             // 边界框 {left, top, right, bottom}
    float score;                // 置信度
    ponit_t ponit[5];           // 5个关键点
} retinaface_object_t;
```

---

## 6. 疲劳检测详细流程

```
RetinaFace 人脸检测
  │
  ├─ letterbox 预处理（保持宽高比缩放 + 填充）
  ├─ RKNN 推理（零拷贝输入输出）
  ├─ 后处理：解码框 + 置信度过滤 + NMS
  └─ 输出：人脸边界框 + 5个关键点
      │
      ▼
PFLD 关键点检测（对每张人脸）
  │
  ├─ 根据检测框裁剪人脸 ROI
  ├─ 缩放到 112x112
  ├─ RKNN 推理
  └─ 输出：106个关键点坐标
      │
      ▼
疲劳指标计算
  │
  ├─ EAR 计算（左右眼各6个关键点）
  │   EAR = (||p2-p6|| + ||p3-p5||) / (2 * ||p1-p4||)
  │   阈值: < 0.22 判定闭眼
  │
  ├─ MAR 计算（嘴巴6个关键点）
  │   MAR = (||p2-p8|| + ||p3-p7|| + ||p4-p6||) / (2 * ||p1-p9||)
  │   阈值: > 0.60 判定张嘴
  │
  ├─ PERCLOS 计算（滑动窗口200帧）
  │   PERCLOS = 闭眼帧数 / 总帧数
  │   阈值: > 0.5 判定疲劳
  │   保护: 缓冲区 < 100帧时不计算
  │
  ├─ 连续闭眼计数
  │   EAR < 0.22 → +1
  │   EAR ≥ 0.22 → max(0, -1)
  │   阈值: ≥ 15帧判定疲劳
  │
  └─ 连续张嘴计数
      MAR > 0.60 → +1
      MAR ≤ 0.60 → max(0, -1)
      阈值: ≥ 20帧判定疲劳
```

---

## 7. 手势识别流程

```
QTimer (1秒间隔)                           // camerapage.cpp:L281
  │
  ├─ 检查: m_cloudInFlight == false?       // 上一次是否完成
  ├─ 检查: m_lastFrame.isNull() == false?  // 是否有图像
  │
  ▼
BaiduGestureClient::infer(m_lastFrame)     // baidu_gesture_client.cpp
  │
  ├─ QImage → JPEG 编码 (质量75)
  ├─ 检查 access_token 是否有效
  │   ├─ 无效 → requestToken()
  │   │   ├─ HTTP POST → 百度OAuth2
  │   │   └─ 保存 token + 过期时间
  │   └─ 有效 → requestGesture(jpegBytes)
  │       ├─ JPEG → Base64 → URL编码
  │       ├─ HTTP POST → 百度手势API
  │       └─ 解析 JSON 响应
  │           └─ 提取 classname + probability
  │
  ▼
emit inferenceFinished(ok, lines)          // 返回识别结果
  │
  ▼
processGestureResult(lines)                // camerapage.cpp:L312
  │
  ├─ 关键词匹配（FIST/FIVE/ONE/TWO/OK/...）
  ├─ 无匹配 → 不发射信号
  └─ 有匹配 → emit gestureDetected(gestureName)
      │
      ▼
MainWindow 接收                            // mainwindow.cpp:L239
  │
  ├─ 手势→动作映射:
  │   Fist → pause (暂停)
  │   Five → play  (播放)
  │   One  → prev  (上一首)
  │   Two  → next  (下一首)
  │
  ├─ 执行音乐控制
  └─ 组装JSON发送串口
      {"type":"gesture","data":{"gesture":"Fist","action":"pause"}}
```

---

## 8. 生命周期与资源释放

### 8.1 正常退出

```
CameraPage::~CameraPage()                   // camerapage.cpp:L300
  └─ m_worker->stop()                       // 设置 m_running = false
      │
      ▼ (采集线程循环退出)
      │
  m_runner.deinit()                         // 释放 RKNN 模型
  │   ├─ release_retinaface_model()         // 释放 RetinaFace
  │   └─ m_pfldModel->deinit()             // 释放 PFLD
  │
  m_service.shutdown()                      // 关闭摄像头
  │   ├─ RK_MPI_VI_DisableChn(0, 0)
  │   ├─ RK_MPI_VI_DisableDev(0)
  │   ├─ SAMPLE_COMM_ISP_Stop(0)
  │   └─ RK_MPI_SYS_Exit()
  │
  emit finished()                           // 通知线程可退出
      │
      ▼
  thread->quit()                            // QThread 退出事件循环
  worker->deleteLater()                     // 延迟删除 Worker
  thread->deleteLater()                     // 延迟删除 Thread
```

### 8.2 信号连接与自动清理

```cpp
// camerapage.cpp:L219-225
connect(thread, &QThread::started, worker, &CameraCaptureWorker::start);
connect(this, &CameraPage::destroyed, worker, &CameraCaptureWorker::stop);
connect(this, &CameraPage::destroyed, thread, &QThread::quit);
connect(worker, &CameraCaptureWorker::finished, thread, &QThread::quit);
connect(worker, &CameraCaptureWorker::finished, worker, &CameraCaptureWorker::deleteLater);
connect(thread, &QThread::finished, thread, &QThread::deleteLater);
```

---

## 9. 关键技术细节

### 9.1 跨线程信号注册

```cpp
// camerapage.cpp:L146-147
qRegisterMetaType<QVector<CameraDetectionOverlay>>("QVector<CameraDetectionOverlay>");
qRegisterMetaType<QStringList>("QStringList");
```

由于 `frameReady` 信号携带自定义类型参数，从子线程发射到主线程时使用 `QueuedConnection`，Qt 需要在元类型系统中注册这些类型才能正确序列化和反序列化。

### 9.2 零拷贝 RKNN 推理

RetinaFace 模型使用 RV1106 的零拷贝 API：

```cpp
// retinaface_facenet.h
rknn_tensor_mem *input_mems[1];    // 输入内存（DMA映射）
rknn_tensor_mem *output_mems[3];   // 输出内存（DMA映射）
```

通过 `rknn_create_mem()` 分配的内存与 NPU 共享物理地址，避免数据拷贝。

### 9.3 Letterbox 预处理

RetinaFace 推理前对输入图像进行 letterbox 处理：

```cpp
// retinaface_facenet.h
typedef struct {
    float scale;    // 缩放比例
    int x_pad;      // 水平填充像素
    int y_pad;      // 垂直填充像素
} letterbox_t;
```

推理后需要用 `scale`、`x_pad`、`y_pad` 将检测框坐标映射回原图。

### 9.4 百度API限流机制

```cpp
// camerapage.cpp:L287-289
if (m_cloudInFlight) {
    return;    // 上一次请求未完成，跳过本次
}
```

通过 `m_cloudInFlight` 标志确保同一时间只有一个手势识别请求在飞行中，避免并发请求导致 API 限流或 token 冲突。

### 9.5 PERCLOS 保护机制

```cpp
// fatigue_runner.cpp:L1562
m_perclos = m_eyeStateBuffer.size() < static_cast<size_t>(m_perclosWindow / 2)
                ? 0.0f
                : static_cast<float>(closed_count) / m_eyeStateBuffer.size();
```

缓冲区帧数未达到窗口大小一半（100帧）时，PERCLOS 强制为 0，防止启动初期少量闭眼帧导致误判。

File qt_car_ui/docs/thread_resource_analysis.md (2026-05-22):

# 线程资源管理分析报告

## 1. 线程与进程资源总览

### 1.1 QThread 线程

| 线程 | 创建位置 | 职责 | 生命周期 | 状态 |
|---|---|---|---|---|
| CameraCaptureWorker 线程 | camerapage.cpp:L229 | 摄像头抓帧 + 人脸检测 + 疲劳推理 | CameraPage 存在期间 | ✅ 正常 |

### 1.2 QProcess 子进程

| 进程 | 创建位置 | 职责 | 启动方式 | 状态 |
|---|---|---|---|---|
| m_musicProcess | dashboardpage.cpp:L287 | 音乐播放 | `play <file>` | ⚠️ 有阻塞风险 |
| m_soundProcess (Dashboard) | dashboardpage.cpp:L307 | 音效播放 | `play -q <file>` | ✅ 基本正常 |
| m_soundProcess (Motion) | motionpage.cpp:L218 | 倾覆警告音 | `play -q <file>` | ⚠️ 有阻塞风险 |

### 1.3 网络请求

| 组件 | 创建位置 | 职责 | 超时机制 | 状态 |
|---|---|---|---|---|
| QNetworkAccessManager (GPS) | gpspage.cpp:L112 | 百度静态地图 | ❌ 无超时 | ⚠️ 风险 |
| QNetworkAccessManager (Dashboard) | dashboardpage.cpp:L282 | 百度静态地图 | ❌ 无超时 | ⚠️ 风险 |
| QNetworkAccessManager (BaiduGesture) | baidu_gesture_client.cpp:L88 | 手势识别API | ✅ 15秒超时 | ✅ 正常 |

### 1.4 串口

| 串口 | 创建位置 | 职责 | 状态 |
|---|---|---|---|
| m_serialRx (ttyS1) | mainwindow.cpp:L466 | 接收传感器数据 | ✅ 异步读取 |
| m_serialTx (ttyS0) | mainwindow.cpp:L483 | 发送状态数据 | ✅ 非阻塞写入 |

---

## 2. 🔴 严重问题：主线程阻塞点

### 2.1 CPU 温度读取 — 主线程阻塞 1 秒

**位置**: [dashboardpage.cpp:L651-663](file:///home/xrlt/qt5_car_ui/qt_car_ui/pages/dashboardpage.cpp#L651-663)

```cpp
for (int i = 0; i < 10; i++) {
    QFile tempFile("/sys/class/thermal/thermal_zone0/temp");
    if (tempFile.open(QIODevice::ReadOnly | QIODevice::Text)) {
        QByteArray data = tempFile.readAll().trimmed();
        tempFile.close();
        // ...
    }
    if (i < 9) {
        QThread::msleep(100);  // ← 主线程阻塞 100ms × 9 = 900ms
    }
}
```

**问题**:
- `updateSystemStats()` 由 `m_sysTimer` 每 2 秒在主线程触发
- 循环 10 次读取温度，每次间隔 `QThread::msleep(100)`
- **主线程总共阻塞约 1 秒**，期间 UI 完全无响应
- 这是导致 UI 卡顿 1-2 秒的最直接原因

**优化建议**:
- 温度值变化缓慢，只需读取 1 次即可，无需 10 次采样取最大值
- 如果需要平滑，可用软件滤波（指数移动平均），而非时间换精度

### 2.2 system() 调用 — 主线程阻塞

**位置**: [settingspage.cpp:L164](file:///home/xrlt/qt5_car_ui/qt_car_ui/pages/settingspage.cpp#L164)

```cpp
auto applyVolume = [](int v) {
    int mixerValue = (v * 30) / 100;
    QString cmd = QString("amixer set 'DAC LINEOUT' %1").arg(mixerValue);
    int result = system(cmd.toUtf8().constData());  // ← 主线程阻塞
};
```

**问题**:
- `system()` 是同步调用，会 fork+exec 子进程并等待其完成
- 在嵌入式设备上，`amixer` 执行可能需要 50-200ms
- 每次调节音量都会阻塞主线程

**位置**: [main.cpp:L12](file:///home/xrlt/qt5_car_ui/qt_car_ui/main.cpp#L12)

```cpp
system("RkLunch-stop.sh");  // ← 启动时阻塞，但影响较小
```

**优化建议**:
- 将 `system("amixer ...")` 替换为 `QProcess::startDetached()` 或直接调用 ALSA API
- 或使用 `QProcess` 异步执行

### 2.3 QProcess::waitForFinished() — 主线程阻塞

**位置 1**: [dashboardpage.cpp:L459](file:///home/xrlt/qt5_car_ui/qt_car_ui/pages/dashboardpage.cpp#L459)

```cpp
void DashboardPage::stopMusic() {
    if (m_musicProcess && m_musicProcess->state() == QProcess::Running) {
        m_musicProcess->terminate();
        m_musicProcess->waitForFinished(1000);  // ← 最多阻塞 1 秒
    }
}
```

**位置 2**: [dashboardpage.cpp:L507](file:///home/xrlt/qt5_car_ui/qt_car_ui/pages/dashboardpage.cpp#L507)

```cpp
void DashboardPage::playMusic(int index) {
    if (m_musicProcess && m_musicProcess->state() == QProcess::Running) {
        m_musicProcess->terminate();
        m_musicProcess->waitForFinished(1000);  // ← 最多阻塞 1 秒
    }
    // ...
}
```

**位置 3**: [dashboardpage.cpp:L445](file:///home/xrlt/qt5_car_ui/qt_car_ui/pages/dashboardpage.cpp#L445)

```cpp
void DashboardPage::setFatigueWarning(bool active) {
    if (!active) {
        if (m_soundProcess && m_soundProcess->state() == QProcess::Running) {
            m_soundProcess->kill();
            m_soundProcess->waitForFinished(500);  // ← 最多阻塞 500ms
        }
    }
}
```

**位置 4**: [motionpage.cpp:L325](file:///home/xrlt/qt5_car_ui/qt_car_ui/pages/motionpage.cpp#L325)

```cpp
void MotionPage::stopWarningSound() {
    if (m_soundProcess && m_soundProcess->state() == QProcess::Running) {
        m_soundProcess->kill();
        m_soundProcess->waitForFinished(500);  // ← 最多阻塞 500ms
    }
}
```

**问题**:
- `waitForFinished()` 在主线程中最多阻塞指定毫秒数
- 如果 `play` 进程未正常退出，主线程会被卡住
- 切歌时 `playMusic()` 先 `terminate` + `waitForFinished(1000)`，再 `start`，可能造成 1 秒卡顿

**优化建议**:
- 使用 `QProcess::kill()` 代替 `terminate()`（`play` 可能不响应 SIGTERM）
- 不使用 `waitForFinished()`，改用信号槽异步处理：
  ```cpp
  m_musicProcess->kill();
  connect(m_musicProcess, &QProcess::finished, this, [this]() {
      m_musicProcess->start("play", ...);
  }, Qt::UniqueConnection);
  ```

---

## 3. 🟡 中等问题：资源竞争与生命周期

### 3.1 QProcess 重复启动风险

**位置**: [dashboardpage.cpp:L507-530](file:///home/xrlt/qt5_car_ui/qt_car_ui/pages/dashboardpage.cpp#L507-530)

```cpp
void DashboardPage::playMusic(int index) {
    // 先终止旧进程
    if (m_musicProcess && m_musicProcess->state() == QProcess::Running) {
        m_musicProcess->terminate();
        m_musicProcess->waitForFinished(1000);
    }
    stopMusic();  // ← 这里又会调用 terminate + waitForFinished
    // ...
    m_musicProcess->start("play", QStringList() << m_musicFiles[index]);
}
```

**问题**:
- `playMusic()` 内部先调用 `terminate + waitForFinished`，然后又调用 `stopMusic()`
- `stopMusic()` 内部也有 `terminate + waitForFinished`
- **双重终止**，且 `stopMusic()` 中 `m_isPlaying = false` 会影响后续逻辑

### 3.2 音效与音乐共用 QProcess 的冲突

**位置**: dashboardpage.cpp

```
m_musicProcess → play song.mp3      (长时间运行)
m_soundProcess → play -q effect.mp3  (短时间运行)
```

**问题**:
- `playSound()` 检查 `m_soundProcess->state() == Running` 时跳过，这是正确的
- 但 `nextSong()` / `prevSong()` 先播放音效，再调用 `playMusic()`
- 音效和音乐使用不同的 QProcess，不存在进程级冲突 ✅

### 3.3 百度地图请求无超时

**位置**: [gpspage.cpp:L165-172](file:///home/xrlt/qt5_car_ui/qt_car_ui/pages/gpspage.cpp#L165-172) 和 [dashboardpage.cpp:L361-368](file:///home/xrlt/qt5_car_ui/qt_car_ui/pages/dashboardpage.cpp#L361-368)

```cpp
QNetworkRequest request(url);
auto *reply = m_network->get(request);
connect(reply, &QNetworkReply::finished, this, [this, reply]() {
    // 处理响应
    reply->deleteLater();
});
```

**问题**:
- 没有设置请求超时
- 如果网络不可达，reply 会一直等待直到系统 TCP 超时（可能 30-120 秒）
- 期间 reply 对象不会被释放，占用内存
- 多次触发会累积未完成的 reply

**对比**: 百度手势 API 有 15 秒超时 ✅

```cpp
// baidu_gesture_client.cpp:L259-267
auto *gestureTimeout = new QTimer(m_gestureReply);
gestureTimeout->setSingleShot(true);
gestureTimeout->setInterval(15000);
connect(gestureTimeout, &QTimer::timeout, m_gestureReply, [reply = m_gestureReply]() {
    if (reply && reply->isRunning()) {
        reply->abort();
    }
});
gestureTimeout->start();
```

**优化建议**: 为地图请求添加同样的超时机制

---

## 4. 🟢 正常：线程生命周期管理

### 4.1 CameraCaptureWorker 线程

```cpp
// camerapage.cpp:L229-237
connect(thread, &QThread::started, worker, &CameraCaptureWorker::start);
connect(this, &CameraPage::destroyed, worker, &CameraCaptureWorker::stop);
connect(this, &CameraPage::destroyed, thread, &QThread::quit);
connect(worker, &CameraCaptureWorker::finished, thread, &QThread::quit);
connect(worker, &CameraCaptureWorker::finished, worker, &CameraCaptureWorker::deleteLater);
connect(thread, &QThread::finished, thread, &QThread::deleteLater);
```

**分析**: ✅ 生命周期管理正确
- `destroyed` 信号确保 CameraPage 销毁时线程退出
- `finished` → `quit` → `deleteLater` 链路完整
- `m_running` 标志可安全退出循环

### 4.2 串口读取

```cpp
// mainwindow.cpp:L477
connect(m_serialRx, &QSerialPort::readyRead, this, &MainWindow::handleSerialReadyRead);
```

**分析**: ✅ 异步读取，不阻塞主线程
- `readyRead` 信号驱动，事件循环中处理
- 缓冲区按 `\n` 分割，处理逻辑轻量

### 4.3 串口写入

```cpp
// mainwindow.cpp:L603-607
m_serialTx->write(data);
m_serialTx->flush();
```

**分析**: ✅ 非阻塞
- `write()` 将数据写入 Qt 缓冲区
- `flush()` 立即发送，串口写入通常很快

---

## 5. 定时器资源统计

| 定时器 | 位置 | 间隔 | 运行线程 | 备注 |
|---|---|---|---|---|
| m_clockTimer | mainwindow.cpp:L340 | 1s | 主线程 | ✅ 轻量 |
| m_recTimer | mainwindow.cpp:L346 | 1s | 主线程 | ✅ 轻量 |
| m_dotTimer | mainwindow.cpp:L350 | 500ms | 主线程 | ✅ 轻量 |
| m_networkCheckTimer | mainwindow.cpp:L355 | 5s | 主线程 | ⚠️ 触发网络请求 |
| m_cloudTimer | camerapage.cpp:L291 | 1s | 主线程 | ⚠️ 触发百度API |
| m_sysTimer | dashboardpage.cpp:L319 | 2s | 主线程 | 🔴 触发1秒阻塞 |
| m_fatigueWarningTimer | dashboardpage.cpp:L310 | 5s | 主线程 | ✅ 轻量 |
| m_progressTimer | dashboardpage.cpp:L488 | 1s | 主线程 | ✅ 轻量 |
| m_flashTimer | motionpage.cpp:L197 | 400ms | 主线程 | ✅ 轻量 |
| m_soundRepeatTimer | motionpage.cpp:L219 | 3s | 主线程 | ✅ 轻量 |

---

## 6. 问题优先级与修复建议

### 🔴 P0：必须修复（直接导致 UI 卡顿）

| # | 问题 | 位置 | 阻塞时间 | 修复方案 |
|---|---|---|---|---|
| 1 | CPU温度读取循环 sleep | dashboardpage.cpp:L651-663 | **~1秒** | 改为单次读取 + 软件滤波 |
| 2 | playMusic 中 waitForFinished | dashboardpage.cpp:L507 | **最多1秒** | 异步处理，用 finished 信号 |
| 3 | stopMusic 中 waitForFinished | dashboardpage.cpp:L526 | **最多1秒** | 异步处理 |

### 🟡 P1：建议修复（潜在卡顿或资源泄漏）

| # | 问题 | 位置 | 修复方案 |
|---|---|---|---|
| 4 | system() 同步调用 amixer | settingspage.cpp:L164 | 改用 QProcess 异步或 ALSA API |
| 5 | 地图请求无超时 | gpspage.cpp:L165, dashboardpage.cpp:L361 | 添加 10 秒超时 QTimer |
| 6 | playMusic 双重终止 | dashboardpage.cpp:L507-514 | 去掉冗余的 stopMusic 调用 |
| 7 | setFatigueWarning waitForFinished | dashboardpage.cpp:L445 | 异步处理 |
| 8 | stopWarningSound waitForFinished | motionpage.cpp:L325 | 异步处理 |

### 🟢 P2：优化建议

| # | 问题 | 位置 | 修复方案 |
|---|---|---|---|
| 9 | 非活跃页面仍占用采集线程 | camerapage.cpp:L61 | ✅ 已通过 setActive 修复 |
| 10 | 地图请求可能累积未完成 reply | gpspage.cpp, dashboardpage.cpp | 请求前 abort 上一个 reply |

---

## 7. 最可能导致 UI 卡顿 1-2 秒的根因

按影响程度排序：

```
1. m_sysTimer 每2秒触发 updateSystemStats()
   └─ QThread::msleep(100) × 9 = 900ms 阻塞
   └─ 每2秒卡顿1秒，UI 帧率从 60fps 降到 ~1fps

2. 切歌时 playMusic() 调用链：
   └─ terminate + waitForFinished(1000) = 最多1秒
   └─ stopMusic() 再次 terminate + waitForFinished(1000) = 最多1秒
   └─ 总计最多 2 秒阻塞

3. 音量调节时 system("amixer ...")
   └─ fork+exec 等待 = 50-200ms
   └─ 多次快速点击会累积
```

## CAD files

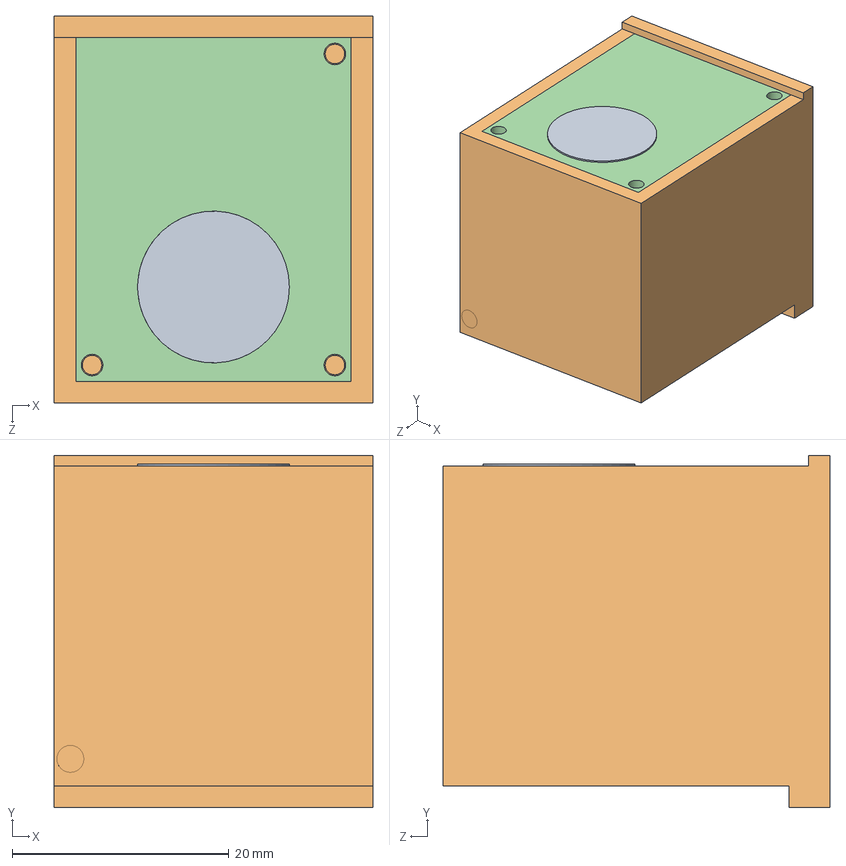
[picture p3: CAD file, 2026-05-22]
3d_model_assets/摄像头装配体.SLDASM
29.4 x 32.5 x 35.7 mm
摄像头
摄像头外壳^摄像头装配体
10-3-3磁铁^摄像头装配体 x 2
摄像头盖板^摄像头装配体

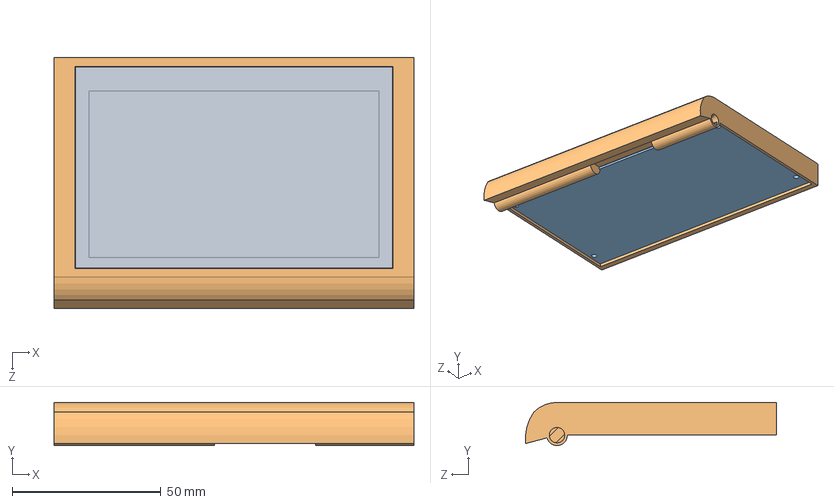
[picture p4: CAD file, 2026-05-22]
3d_model_assets/屏幕固定装配体.SLDASM
120.9 x 14.5 x 84.3 mm
RGB屏幕
屏幕固定转轴
屏幕压板^屏幕固定装配体

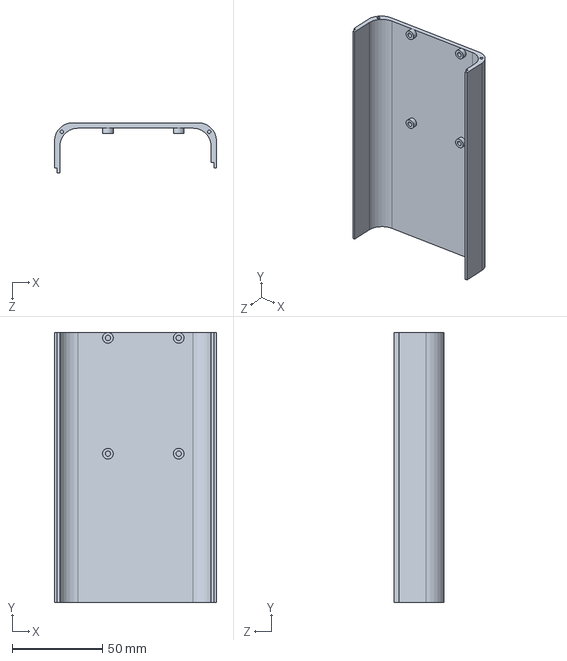
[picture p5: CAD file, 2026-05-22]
3d_model_assets/下盖.SLDPRT
90.0 x 150.0 x 28.0 mm

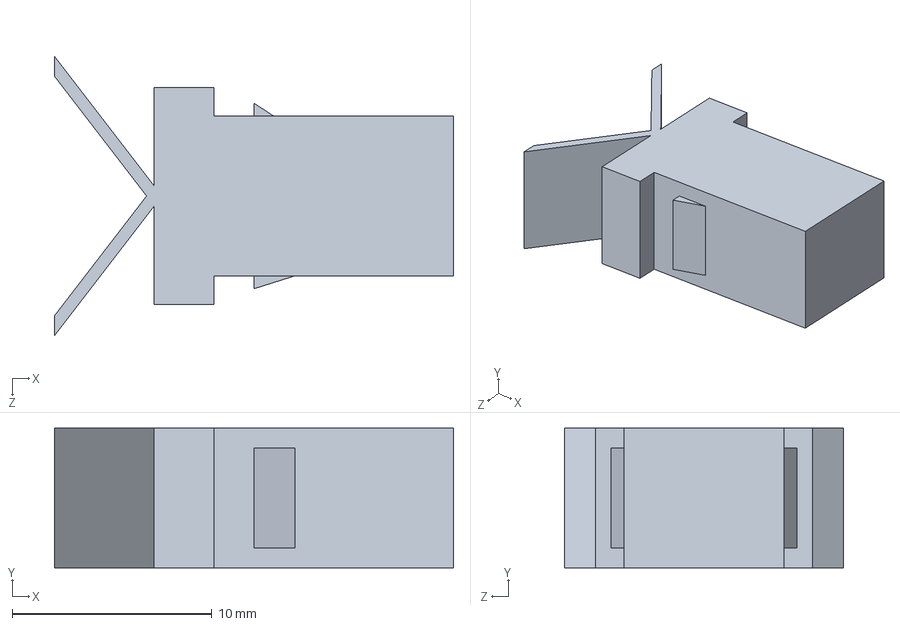
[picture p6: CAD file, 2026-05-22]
3d_model_assets/锁扣母头.SLDPRT
20.0 x 7.00 x 14.0 mm

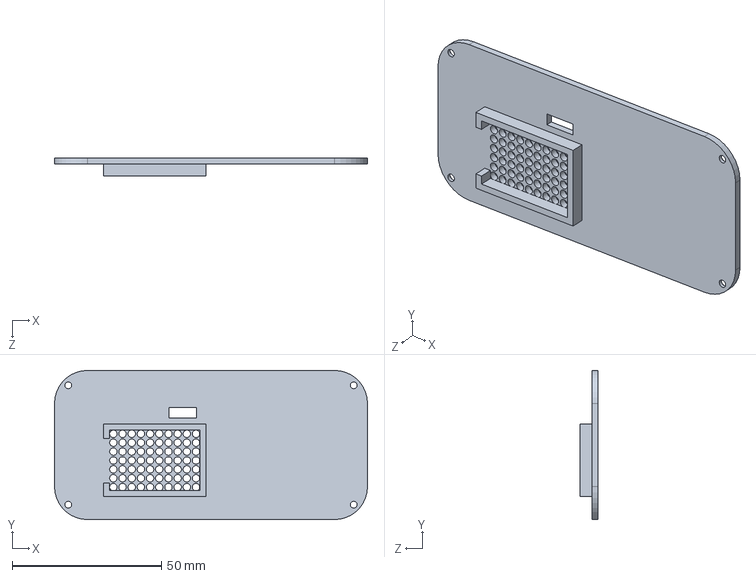
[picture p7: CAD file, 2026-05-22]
3d_model_assets/左盖板.SLDPRT
105.0 x 50.0 x 6.00 mm

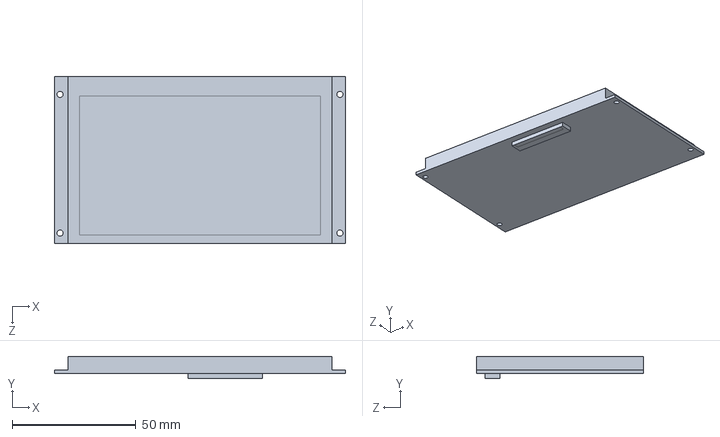
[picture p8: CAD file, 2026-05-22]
3d_model_assets/RGB屏幕.SLDPRT
117.5 x 8.90 x 67.5 mm

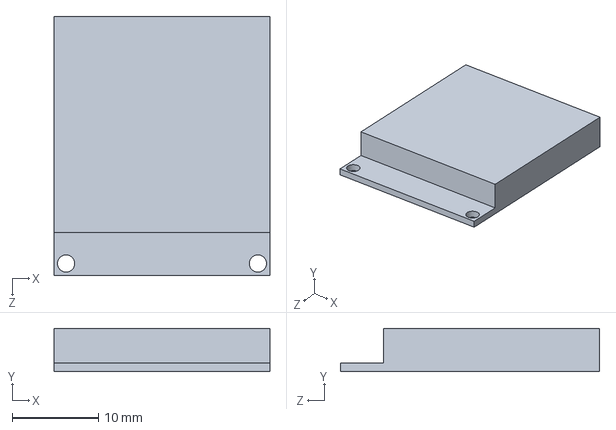
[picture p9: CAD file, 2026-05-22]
3d_model_assets/大夏龙雀GPS模块.SLDPRT
25.0 x 5.00 x 30.0 mm

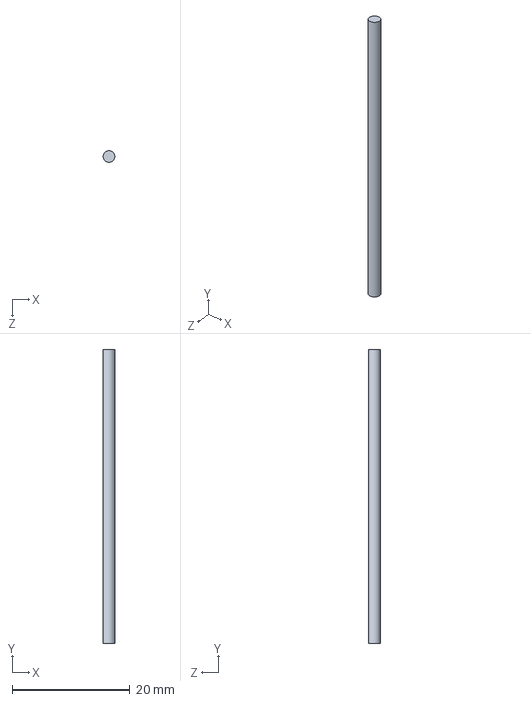
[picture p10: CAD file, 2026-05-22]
3d_model_assets/1.5光轴35长.SLDPRT
2.00 x 50.0 x 2.00 mm

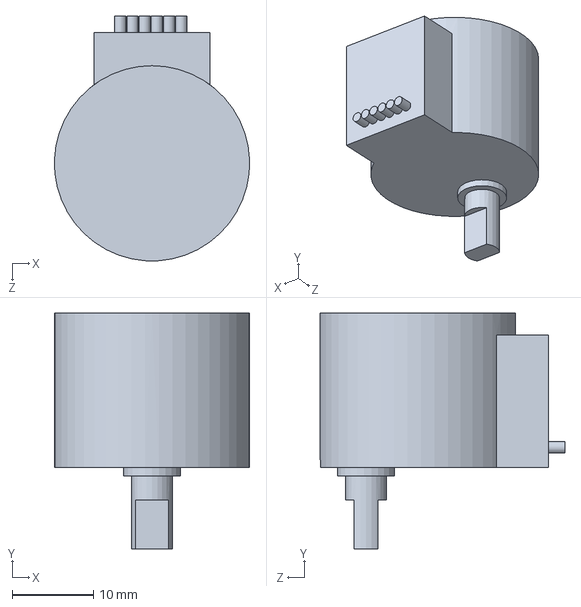
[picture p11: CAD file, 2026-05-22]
3d_model_assets/24步进电机.SLDPRT
24.0 x 29.0 x 30.1 mm

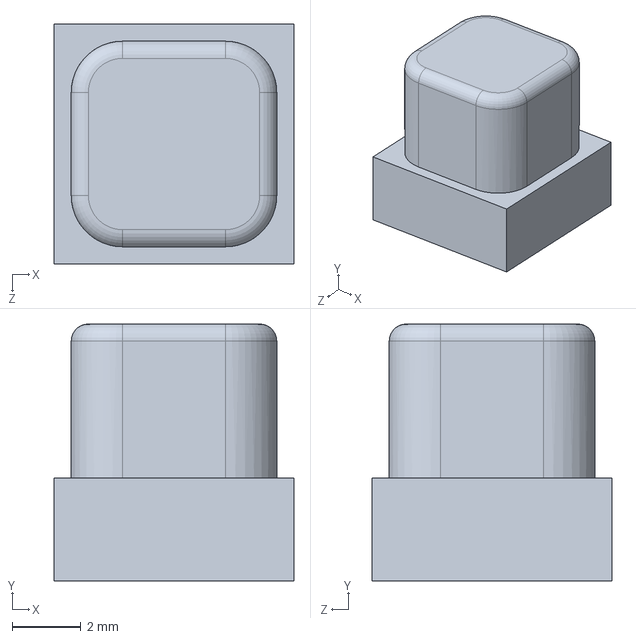
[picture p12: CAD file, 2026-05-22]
3d_model_assets/按键.SLDPRT
7.00 x 7.50 x 7.00 mm

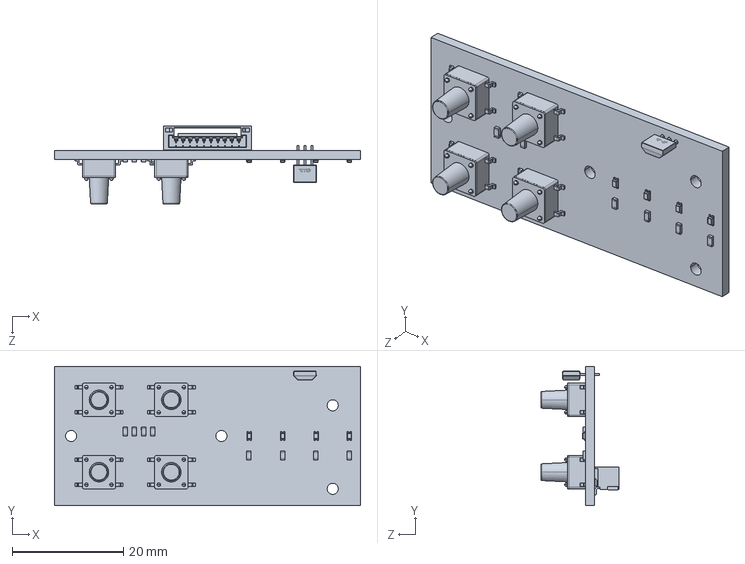
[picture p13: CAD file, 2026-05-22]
3d_model_assets/LED按键驱动板.SLDPRT
55.0 x 25.0 x 14.0 mm

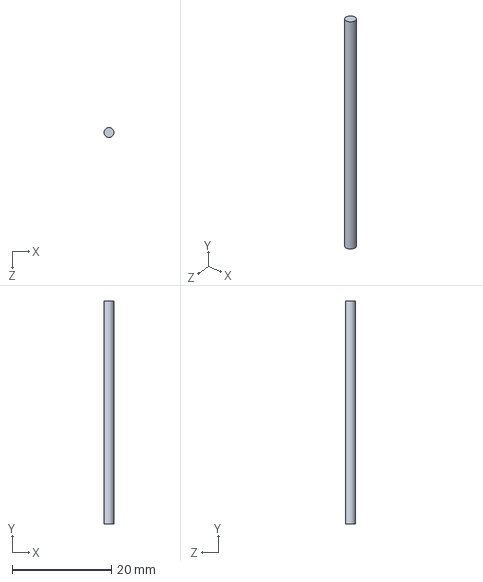
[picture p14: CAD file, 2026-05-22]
3d_model_assets/2光轴45长.SLDPRT
2.00 x 45.0 x 2.00 mm

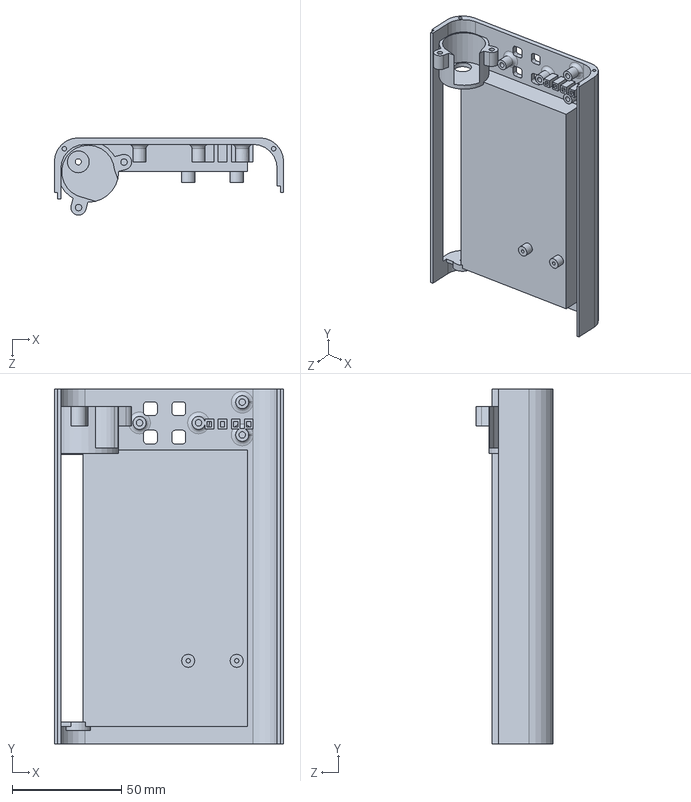
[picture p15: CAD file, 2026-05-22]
3d_model_assets/上盖.SLDPRT
105.0 x 162.5 x 35.4 mm

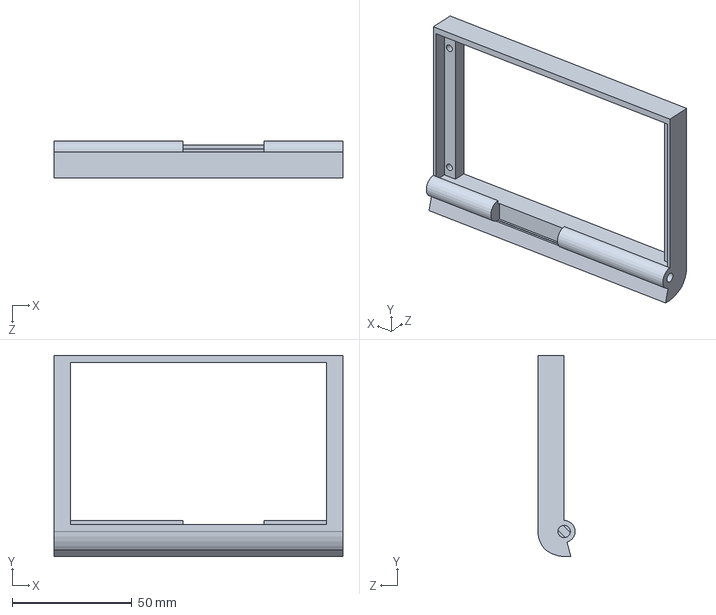
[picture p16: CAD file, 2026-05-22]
3d_model_assets/屏幕固定转轴.SLDPRT
120.9 x 84.3 x 15.6 mm

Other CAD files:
3d_model_assets/锁扣公头.SLDPRT
3d_model_assets/摄像头.SLDPRT
3d_model_assets/右盖板.SLDPRT
3d_model_assets/GB／T283-94圆柱滚子轴承NH202E.SLDPRT
3d_model_assets/2光轴50长.SLDPRT
3d_model_assets/LED驱动板.SLDPRT

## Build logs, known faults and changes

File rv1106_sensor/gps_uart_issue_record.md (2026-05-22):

# GPS 串口无数据问题排查记录

## 背景与现象

在板上调试 GPS 模块时，调试串口只输出初始化日志，之后无更多输出。使用 USB 转串口直接连接 GPS 模块可正常看到 NMEA 数据（默认 9600bps）。板上 UART2（PA2/PA3）看到了外部信号，但 STM32 未收到数据。

## 结论概览

问题根因是 FreeRTOS 任务创建失败导致 GPS 串口转发任务未启动。失败原因是任务栈配置过大导致堆不足，GPS Bridge 任务创建失败。

## 详细排查步骤与验证点

### 步骤 1：确认 GPS 模块输出与波特率

结论：模块输出正常，默认 9600bps。
验证方式：

- USB 转串口直接连接模块输出，能够看到类似以下 NMEA 数据：
  - $GNRMC,,V,,,,,,,,,,N,V*37
  - $GPTXT,01,01,01,ANTENNA OPEN*25
- 说明模块正常发射，板端问题可能是 UART 接收或任务未运行。

### 步骤 2：确认 STM32 串口配置

结论：UART2 波特率已配置为 9600bps，格式为 8N1。
验证方式：

- 查看 USART2 初始化配置（MX_USART2_UART_Init）。
- 确保 BaudRate = 9600。

### 步骤 3：定位串口接收逻辑

结论：UART2 接收在独立任务中阻塞读取，并转发到 UART1。
验证方式：

- 查看 FreeRTOS 任务 StartGpsBridgeTask，使用 HAL_UART_Receive(&huart2, &rx_byte, 1, HAL_MAX_DELAY) 接收数据。

### 步骤 4：验证任务是否真正启动

结论：任务未启动，原因是创建失败。
验证方式：

- 在任务创建处增加失败提示日志，发现打印：
  - GPS Bridge Task Create Failed
- 说明任务创建失败而不是 UART 本身收不到数据。

### 步骤 5：检查堆与任务栈

结论：堆不足，任务栈配置过大。
验证方式：

- 输出系统空闲堆与任务栈水位：
  - heap 仅剩 ~800
  - 新增任务创建失败
- 说明堆分配无法满足新任务的栈需求。

### 步骤 6：调整任务栈大小并验证

结论：缩小任务栈后创建成功，GPS 数据开始收到。
验证方式：

- 调整栈大小：
  - defaultTask：2048 → 1024
  - gpsBridgeTask：512 → 256
  - ledBlinkTask：256 → 128
- 重新运行后不再出现创建失败提示。
- GPS Bridge 任务开始运行，UART2 数据能够转发到 UART1。

## 最终修复内容

1. UART2 波特率设置为 9600。
2. 增加 UART2→UART1 转发任务。
3. 缩小任务栈，确保堆空间充足，任务可创建。

## 诊断打印与栈水位说明

当启用 `INCLUDE_uxTaskGetStackHighWaterMark` 时，可使用栈水位 API 观察任务运行时的最小剩余栈。该值是“历史最低剩余栈”（以字为单位），值越小越接近栈溢出。

### 常用诊断打印示例

```
DBG loop=6 gps_rx=0 led=4 heap=800 stack_def=1706 stack_gps=1706 stack_led=184
```

### 每个字段含义

- loop：主任务循环次数，用于确认主任务在持续运行。
- gps_rx：串口2收到并转发的字节数，用于确认 UART2 接收是否在增长。
- led：LED 线程闪烁次数，用于确认 LED 任务是否在运行。
- heap：FreeRTOS 当前剩余堆空间（字节），用于判断是否存在堆不足导致任务创建失败。
- stack_def：defaultTask 的栈高水位（字为单位），用于评估主任务栈是否充足。
- stack_gps：gpsBridgeTask 的栈高水位（字为单位），用于评估串口转发任务栈是否充足。
- stack_led：ledBlinkTask 的栈高水位（字为单位），用于评估 LED 任务栈是否充足。

### 解读要点

- heap 持续过低或任务创建失败，说明需要减小任务栈或增大堆。
- stack_* 值过小（例如接近 0），说明该任务栈可能不够，需要增大。
- gps_rx 长期为 0，说明 UART2 没收到数据，需检查接线或串口配置。

## 可复用的验证清单

1. USB 转串口确认模块输出正常。
2. 确认 UART2 引脚接线与电平匹配。
3. 确认 UART2 配置波特率、格式一致。
4. 确认 FreeRTOS 任务创建成功。
5. 检查堆空间和任务栈水位是否足够。

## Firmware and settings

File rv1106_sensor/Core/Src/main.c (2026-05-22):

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
/* Includes ------------------------------------------------------------------*/
#include "main.h"
#include "cmsis_os.h"
#include "adc.h"
#include "dma.h"
#include "usart.h"
#include "gpio.h"

/* USER CODE BEGIN Includes */
#include <stdio.h>
#include "bsp_power.h"
#include "soft_i2c.h"
#include "mpu6050.h"
#include "aht30.h"
#include "ina226.h"
#include "gps_module.h"
#include "bsp_adc.h"
#include "stepper.h"
/* USER CODE END Includes */


/* USER CODE BEGIN PV */
SoftI2C_Handle_t hi2c_mpu = {GPIOB, GPIO_PIN_11, GPIOB, GPIO_PIN_10}; // MPU6050: SCL=PB11, SDA=PB10
SoftI2C_Handle_t hi2c_aht = {GPIOC, GPIO_PIN_10, GPIOA, GPIO_PIN_15}; // AHT30: SCL=PC10, SDA=PA15
SoftI2C_Handle_t hi2c_ina = {GPIOC, GPIO_PIN_11, GPIOC, GPIO_PIN_12}; // INA226: SCL=PC11, SDA=PC12
/* USER CODE END PV */

void SystemClock_Config(void);
void MX_FREERTOS_Init(void);
/* USER CODE BEGIN 0 */
#ifdef __GNUC__
/* With GCC, small printf (option LD Linker->Libraries->Small printf
   set to 'Yes') calls __io_putchar() */
int __io_putchar(int ch)
#else
int fputc(int ch, FILE *f)
#endif /* __GNUC__ */
{
  /* Place your implementation of fputc here */
  /* e.g. write a character to the USART1 and Loop until the end of transmission */
  HAL_UART_Transmit(&huart1, (uint8_t *)&ch, 1, HAL_MAX_DELAY);
  return ch;
}

// Support for printf in some GCC environments without syscalls
int _write(int file, char *ptr, int len) {
    HAL_UART_Transmit(&huart1, (uint8_t *)ptr, len, HAL_MAX_DELAY);
    return len;
}
/* USER CODE END 0 */

/**
  * @brief  The application entry point.
  * @retval int
  */
int main(void)
{

  /* MCU Configuration--------------------------------------------------------*/

  /* Reset of all peripherals, Initializes the Flash interface and the Systick. */
  HAL_Init();

  /* Configure the system clock */
  SystemClock_Config();

  /* Initialize all configured peripherals */
  MX_GPIO_Init();
  MX_DMA_Init();
  MX_ADC1_Init();
  MX_USART1_UART_Init();
  MX_USART2_UART_Init();
  MX_USART3_UART_Init();
  /* USER CODE BEGIN 2 */
  printf("\r\n=== STM32 Sensor Hub Test Start ===\r\n");

  // 1. Power Up Sensors
  BSP_Power_Init();
  BSP_Power_SetSensorPower(1);
  BSP_Power_SetRV1106Power(1);
  HAL_Delay(200);

  // 2. Initialize I2C Buses
  SoftI2C_Init(&hi2c_mpu);
  SoftI2C_Init(&hi2c_aht);
  SoftI2C_Init(&hi2c_ina);

  // 3. Initialize Sensors
  if (MPU6050_Init(&hi2c_mpu) == 0) {
      printf("MPU6050 Init OK\r\n");
  }

  if (AHT30_Init(&hi2c_aht) == 0) {
      printf("AHT30 Init OK\r\n");
  }

  if (INA226_Init(&hi2c_ina) == 0) {
      printf("INA226 Init OK\r\n");
  }

  // 4. Initialize Stepper
  Stepper_Init();

  // 5. Initialize GPS (Already powered by SensorPower)
  GPS_Init();

  /* USER CODE END 2 */

  /* Call init function for freertos objects (in cmsis_os2.c) */
  MX_FREERTOS_Init();

  /* Start scheduler */
  osKernelStart();

  /* We should never get here as control is now taken by the scheduler */

  /* Infinite loop */
  /* USER CODE BEGIN WHILE */
  while (1)
  {
    /* USER CODE END WHILE */

    /* USER CODE BEGIN 3 */
  }
  /* USER CODE END 3 */
}

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
/**
  * @brief  Period elapsed callback in non blocking mode
  * @note   This function is called  when TIM6 interrupt took place, inside
  * HAL_TIM_IRQHandler(). It makes a direct call to HAL_IncTick() to increment
  * a global variable "uwTick" used as application time base.
  * @param  htim : TIM handle
  * @retval None
  */
void HAL_TIM_PeriodElapsedCallback(TIM_HandleTypeDef *htim)
{
  if (htim->Instance == TIM6)
  {
    HAL_IncTick();
  }
}

/**
  * @brief  This function is executed in case of error occurrence.
  * @retval None
  */
void Error_Handler(void)
{
  /* USER CODE BEGIN Error_Handler_Debug */
  /* User can add his own implementation to report the HAL error return state */
  __disable_irq();
  while (1)
  {
  }
  /* USER CODE END Error_Handler_Debug */
}
#ifdef USE_FULL_ASSERT
/**
  * @brief  Reports the name of the source file and the source line number
  *         where the assert_param error has occurred.
  * @param  file: pointer to the source file name
  * @param  line: assert_param error line source number
  * @retval None
  */
void assert_failed(uint8_t *file, uint32_t line)
{
  /* USER CODE BEGIN 6 */
  /* User can add his own implementation to report the file name and line number,
     ex: printf("Wrong parameters value: file %s on line %d\r\n", file, line) */
  /* USER CODE END 6 */
}
#endif /* USE_FULL_ASSERT */

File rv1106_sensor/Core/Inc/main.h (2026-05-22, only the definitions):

#define RV1106_POWER_EN_Pin GPIO_PIN_13
#define RV1106_POWER_EN_GPIO_Port GPIOC
#define IN_HALL_ADC1_Pin GPIO_PIN_0
#define IN_HALL_ADC1_GPIO_Port GPIOC
#define IN_HALL_ADC2_Pin GPIO_PIN_1
#define IN_HALL_ADC2_GPIO_Port GPIOC
#define BAT_ADC_EN_Pin GPIO_PIN_3
#define BAT_ADC_EN_GPIO_Port GPIOC
#define BOOST_EN_Pin GPIO_PIN_1
#define BOOST_EN_GPIO_Port GPIOA
#define GPS_TX_Pin GPIO_PIN_2
#define GPS_TX_GPIO_Port GPIOA
#define GPS_RX_Pin GPIO_PIN_3
#define GPS_RX_GPIO_Port GPIOA
#define GPS_WAKE_Pin GPIO_PIN_6
#define GPS_WAKE_GPIO_Port GPIOA
#define STM32_TX_Pin GPIO_PIN_4
#define STM32_TX_GPIO_Port GPIOC
#define STM32_RX_Pin GPIO_PIN_5
#define STM32_RX_GPIO_Port GPIOC
#define MPU6050_SDA_Pin GPIO_PIN_10
#define MPU6050_SDA_GPIO_Port GPIOB
#define MPU6050_SCL_Pin GPIO_PIN_11
#define MPU6050_SCL_GPIO_Port GPIOB
#define AHT30_SDA_Pin GPIO_PIN_15
#define AHT30_SDA_GPIO_Port GPIOA
#define AHT30_SCL_Pin GPIO_PIN_10
#define AHT30_SCL_GPIO_Port GPIOC
#define INA226_SCL_Pin GPIO_PIN_11
#define INA226_SCL_GPIO_Port GPIOC
#define INA226_SDA_Pin GPIO_PIN_12
#define INA226_SDA_GPIO_Port GPIOC
#define STEP_D0_Pin GPIO_PIN_2
#define STEP_D0_GPIO_Port GPIOD
#define STEP_D1_Pin GPIO_PIN_3
#define STEP_D1_GPIO_Port GPIOB
#define STEP_D2_Pin GPIO_PIN_4
#define STEP_D2_GPIO_Port GPIOB
#define STEP_D3_Pin GPIO_PIN_5
#define STEP_D3_GPIO_Port GPIOB
#define LED_OUT1_Pin GPIO_PIN_6
#define LED_OUT1_GPIO_Port GPIOB
#define LED_OUT2_Pin GPIO_PIN_7
#define LED_OUT2_GPIO_Port GPIOB
#define LED_OUT3_Pin GPIO_PIN_8
#define LED_OUT3_GPIO_Port GPIOB
#define LED_OUT4_Pin GPIO_PIN_9
#define LED_OUT4_GPIO_Port GPIOB

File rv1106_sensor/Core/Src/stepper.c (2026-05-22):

#include "stepper.h"
#include <stdlib.h>

// Stepper Sequence (4-step single phase)
// D0, D1, D2, D3
static const uint8_t step_seq[4][4] = {
    {1, 0, 0, 0},
    {0, 1, 0, 0},
    {0, 0, 1, 0},
    {0, 0, 0, 1}
};

// 全局步数计数器
static int32_t global_step_count = 0;
// 假设每转步数 (根据实际电机调整，28BYJ-48 通常为 2048)
#define STEPS_PER_REV 2048.0f

void Stepper_Init(void) {
    // Stop Motor
    HAL_GPIO_WritePin(STEP_D0_GPIO_Port, STEP_D0_Pin, GPIO_PIN_RESET);
    HAL_GPIO_WritePin(STEP_D1_GPIO_Port, STEP_D1_Pin, GPIO_PIN_RESET);
    HAL_GPIO_WritePin(STEP_D2_GPIO_Port, STEP_D2_Pin, GPIO_PIN_RESET);
    HAL_GPIO_WritePin(STEP_D3_GPIO_Port, STEP_D3_Pin, GPIO_PIN_RESET);
}

static void Stepper_SetPhase(uint8_t step) {
    HAL_GPIO_WritePin(STEP_D0_GPIO_Port, STEP_D0_Pin, step_seq[step][0] ? GPIO_PIN_SET : GPIO_PIN_RESET);
    HAL_GPIO_WritePin(STEP_D1_GPIO_Port, STEP_D1_Pin, step_seq[step][1] ? GPIO_PIN_SET : GPIO_PIN_RESET);
    HAL_GPIO_WritePin(STEP_D2_GPIO_Port, STEP_D2_Pin, step_seq[step][2] ? GPIO_PIN_SET : GPIO_PIN_RESET);
    HAL_GPIO_WritePin(STEP_D3_GPIO_Port, STEP_D3_Pin, step_seq[step][3] ? GPIO_PIN_SET : GPIO_PIN_RESET);
}

static void Stepper_SetPhaseWithSequence(uint8_t step, const uint8_t sequence[4]) {
    // 根据 sequence 映射 step (0-3) 到实际的相位索引
    // sequence[step] 返回要激活的实际相位 (0, 1, 2, 3)
    // 默认 sequence 是 {0, 1, 2, 3}
    // 另一种可能是 {0, 2, 1, 3} 等等
    
    uint8_t actual_phase = sequence[step];
    
    // 使用原始的 step_seq 来激活对应的物理引脚
    // step_seq[actual_phase] 对应 {D0, D1, D2, D3} 的电平
    HAL_GPIO_WritePin(STEP_D0_GPIO_Port, STEP_D0_Pin, step_seq[actual_phase][0] ? GPIO_PIN_SET : GPIO_PIN_RESET);
    HAL_GPIO_WritePin(STEP_D1_GPIO_Port, STEP_D1_Pin, step_seq[actual_phase][1] ? GPIO_PIN_SET : GPIO_PIN_RESET);
    HAL_GPIO_WritePin(STEP_D2_GPIO_Port, STEP_D2_Pin, step_seq[actual_phase][2] ? GPIO_PIN_SET : GPIO_PIN_RESET);
    HAL_GPIO_WritePin(STEP_D3_GPIO_Port, STEP_D3_Pin, step_seq[actual_phase][3] ? GPIO_PIN_SET : GPIO_PIN_RESET);
}

void Stepper_SingleStepWithSequence(int direction, const uint8_t sequence[4]) {
    static int current_step = 0;
    
    if (direction > 0) direction = 1;
    if (direction < 0) direction = -1;
    if (direction == 0) return;

    current_step += direction;
    if (current_step > 3) current_step = 0;
    if (current_step < 0) current_step = 3;
    
    Stepper_SetPhaseWithSequence(current_step, sequence);
}

void Stepper_ActivatePhase(uint8_t phase) {
    if (phase > 3) phase = 0;
    Stepper_SetPhase(phase);
}

void Stepper_SingleStep(int direction) {
    static int current_step = 0;
    
    // Normalize direction
    if (direction > 0) direction = 1;
    if (direction < 0) direction = -1;
    if (direction == 0) return;

    current_step += direction;
    global_step_count += direction; // 更新全局位置

    if (current_step > 3) current_step = 0;
    if (current_step < 0) current_step = 3;
    
    Stepper_SetPhase(current_step);
}

void Stepper_ResetPosition(void) {
    global_step_count = 0;
}

float Stepper_GetAngle(void) {
    float angle = global_step_count * (360.0f / STEPS_PER_REV);
    return angle;
}

void Stepper_SetAngle(float angle) {
    float current_angle = Stepper_GetAngle();
    float diff = angle - current_angle;
    
    int steps = (int)(diff * (STEPS_PER_REV / 360.0f));
    
    int direction = (steps > 0) ? 1 : -1;
    steps = abs(steps);
    
    for (int i = 0; i < steps; i++) {
        Stepper_SingleStep(direction);
        HAL_Delay(5);
    }
}

void Stepper_Step(int steps, uint32_t delay_ms) {
    int direction = (steps > 0) ? 1 : -1;
    steps = abs(steps);

    for (int i = 0; i < steps; i++) {
        Stepper_SingleStep(direction);
        HAL_Delay(delay_ms);
    }
    
    // 可选：运动后关闭线圈以省电
    // Stepper_Init(); 
}

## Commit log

2026-05-22 feat: initial commit - Car Camera Shutter Alert system
    - RV1106 Qt5 UI with fatigue detection, gesture recognition, GPS, sensors
    - STM32L431 FreeRTOS firmware with MPU6050, AHT30, INA226, GPS drivers
    - Serial JSON protocol between STM32 and RV1106
    - 3D model assets and PCB design files
    - MIT License
    [1.5光轴35长.SLDPRT, 24步进电机.SLDPRT, 2光轴45长.SLDPRT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]
2026-05-22 fix: convert qt_car_ui and rv1106_sensor from submodules to regular directories
    [aht30.c, bsp_adc.c, bsp_power.c]
2026-05-22 chore(gitignore): 移除PCB项目临时文件匹配规则
    删除了冗余的PCB/*.epro2临时文件忽略配置

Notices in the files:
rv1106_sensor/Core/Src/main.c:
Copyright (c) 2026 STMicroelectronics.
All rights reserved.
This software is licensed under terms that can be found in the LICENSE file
